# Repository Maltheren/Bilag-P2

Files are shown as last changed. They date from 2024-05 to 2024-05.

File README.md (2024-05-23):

# Bilag til P2 projektet ESD210
Alle eksterne bilag til P2 projektet for ESD210 hvor der kan findes følgende mapper:

### Kicad filer
Alle kredsløbsdiagrammer samt PCB designs. Under mappen /PDF kan alle schematics findes i pdf format.

### Kode produkt
De endelige 3 sketches for produktet. Det anbefales at åbne dem via platformIO.
Ellers kan den primære funktionskode findes i /src/main.cpp, samt de udviklede libraries under /lib.
Eksternt brugte libraries i dette projekt er:
- "Arduino.h"
- "RF24.h"

### Tests
Her forefindes de forskellige tests opdelt som enten samlet, Klokke eller MKF

### PC oscilloskop
For at visualisere de samples der tages af arduinoen på MKF-modulet benyttes følgende værktøj
https://x-io.co.uk/serial-oscilloscope/

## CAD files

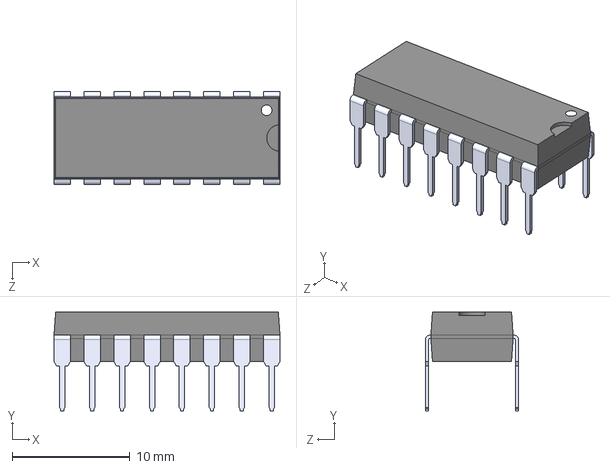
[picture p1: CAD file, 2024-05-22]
Kicad filer/MKFmodul/DG445CJ/DG445CJ.step
19.2 x 8.38 x 7.90 mm

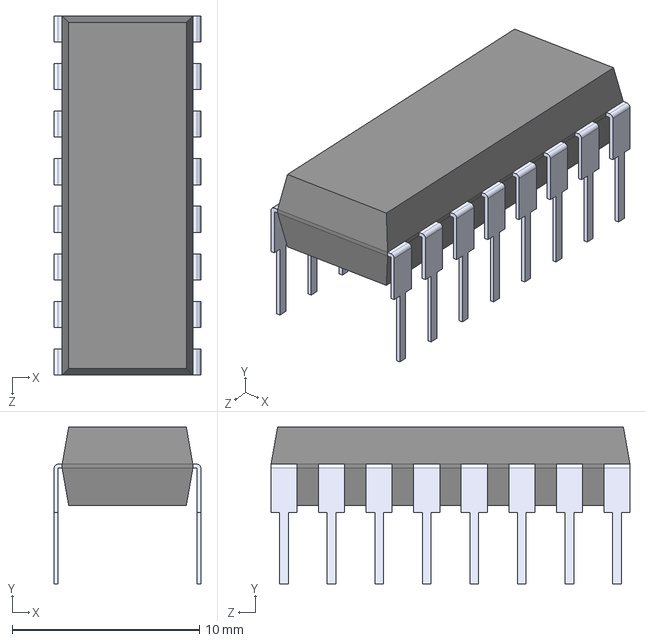
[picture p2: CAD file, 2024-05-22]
Kicad filer/PowerAddOn/PowerAddOn/MAX743CPE/MAX743CPE.step
7.83 x 8.38 x 19.2 mm

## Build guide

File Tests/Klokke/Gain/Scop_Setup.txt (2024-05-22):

TIME STEP:
125 = 1ms

VOLTAGE STEP:
CH1:  32 = 1V
CH2:  32 = 0.1V
GND	34	100
N	CH1	CH2

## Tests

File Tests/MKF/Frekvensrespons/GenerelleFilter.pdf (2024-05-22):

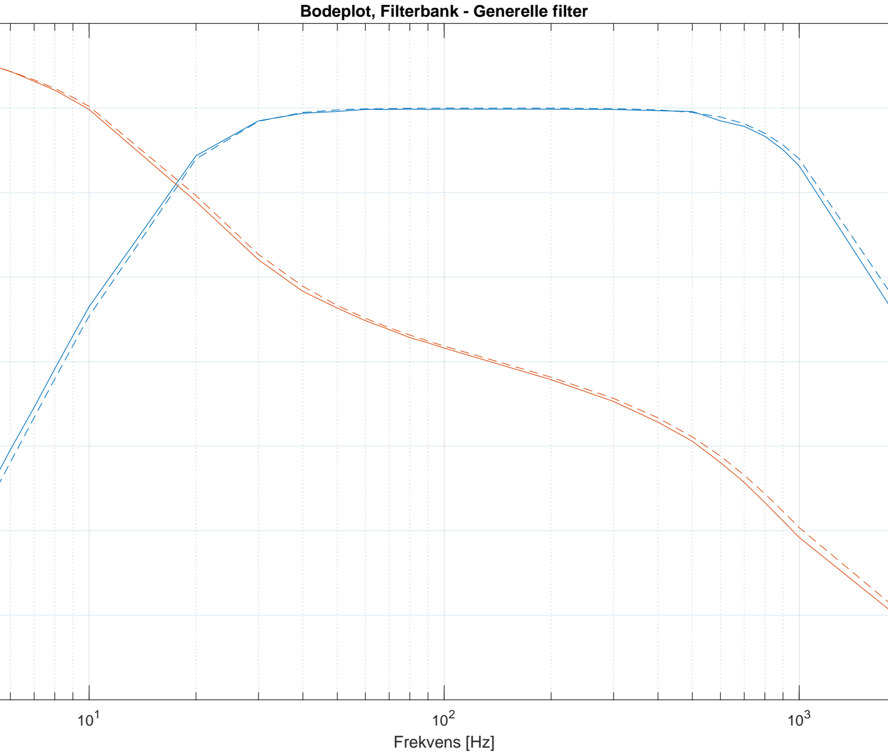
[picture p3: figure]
Frekvens [Hz]; Bodeplot, Filterbank - Generelle filter

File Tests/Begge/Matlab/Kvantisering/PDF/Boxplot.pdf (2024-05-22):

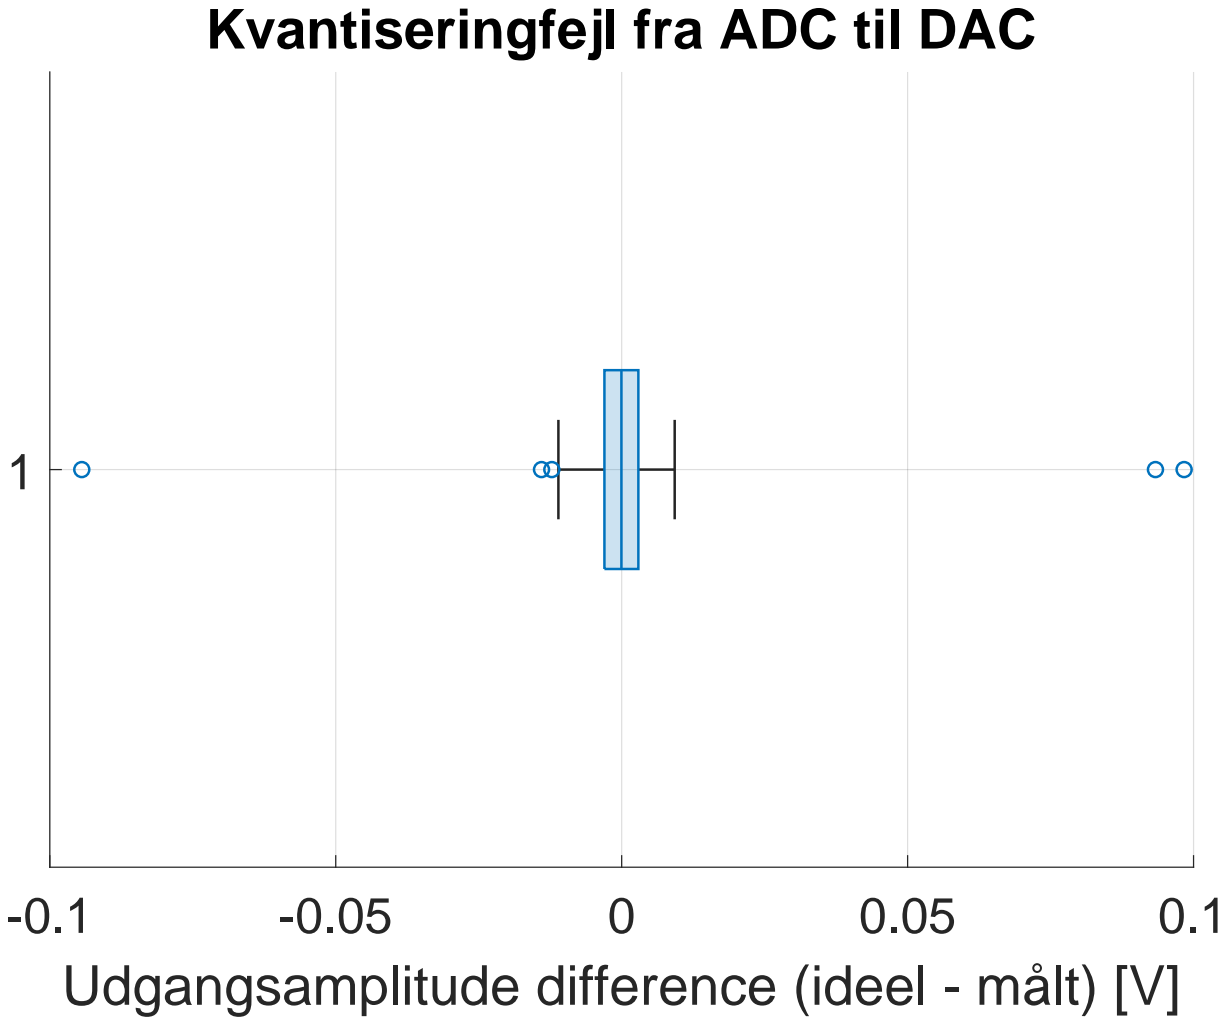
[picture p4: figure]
Kvantiseringfejl fra ADC til DAC

Udgangsamplitude difference (ideel - målt) [V]

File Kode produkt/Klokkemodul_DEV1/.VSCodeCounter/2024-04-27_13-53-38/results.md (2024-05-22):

# Summary

Date : 2024-04-27 13:53:38

Directory c:\\Users\\Malthe Sennels\\Documents\\ESD210\\Kode_Produkt\\Klokkemodul_DEV1

Total : 17 files,  393 codes, 148 comments, 179 blanks, all 720 lines

Summary / [Details](details.md) / [Diff Summary](diff.md) / [Diff Details](diff-details.md)

## Languages
| language | files | code | comment | blank | total |
| :--- | ---: | ---: | ---: | ---: | ---: |
| C++ | 15 | 377 | 137 | 173 | 687 |
| Ini | 1 | 14 | 11 | 5 | 30 |
| Markdown | 1 | 2 | 0 | 1 | 3 |

## Directories
| path | files | code | comment | blank | total |
| :--- | ---: | ---: | ---: | ---: | ---: |
| . | 17 | 393 | 148 | 179 | 720 |
| . (Files) | 1 | 14 | 11 | 5 | 30 |
| lib | 15 | 328 | 107 | 136 | 571 |
| lib\\DAC | 2 | 46 | 0 | 15 | 61 |
| lib\\GainController | 2 | 44 | 5 | 18 | 67 |
| lib\\HAL | 2 | 38 | 24 | 34 | 96 |
| lib\\JobQuerer | 2 | 63 | 39 | 24 | 126 |
| lib\\JobQuerer\\src | 2 | 63 | 39 | 24 | 126 |
| lib\\Ringbuffer | 2 | 33 | 11 | 7 | 51 |
| lib\\TurboAnalogRead | 3 | 43 | 26 | 22 | 91 |
| lib\\TurboAnalogRead (Files) | 1 | 2 | 0 | 1 | 3 |
| lib\\TurboAnalogRead\\src | 2 | 41 | 26 | 21 | 88 |
| lib\\X9C104 | 2 | 61 | 2 | 16 | 79 |
| src | 1 | 51 | 30 | 38 | 119 |

Summary / [Details](details.md) / [Diff Summary](diff.md) / [Diff Details](diff-details.md)

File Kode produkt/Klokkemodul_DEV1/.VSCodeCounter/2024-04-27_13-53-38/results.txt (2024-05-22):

Date : 2024-04-27 13:53:38
Directory : c:\Users\Malthe Sennels\Documents\ESD210\Kode_Produkt\Klokkemodul_DEV1
Total : 17 files,  393 codes, 148 comments, 179 blanks, all 720 lines

Languages
+----------+------------+------------+------------+------------+------------+
| language | files      | code       | comment    | blank      | total      |
+----------+------------+------------+------------+------------+------------+
| C++      |         15 |        377 |        137 |        173 |        687 |
| Ini      |          1 |         14 |         11 |          5 |         30 |
| Markdown |          1 |          2 |          0 |          1 |          3 |
+----------+------------+------------+------------+------------+------------+

Directories
+--------------------------------------------------------------------------------------------------------------+------------+------------+------------+------------+------------+
| path                                                                                                         | files      | code       | comment    | blank      | total      |
+--------------------------------------------------------------------------------------------------------------+------------+------------+------------+------------+------------+
| .                                                                                                            |         17 |        393 |        148 |        179 |        720 |
| . (Files)                                                                                                    |          1 |         14 |         11 |          5 |         30 |
| lib                                                                                                          |         15 |        328 |        107 |        136 |        571 |
| lib\DAC                                                                                                      |          2 |         46 |          0 |         15 |         61 |
| lib\GainController                                                                                           |          2 |         44 |          5 |         18 |         67 |
| lib\HAL                                                                                                      |          2 |         38 |         24 |         34 |         96 |
| lib\JobQuerer                                                                                                |          2 |         63 |         39 |         24 |        126 |
| lib\JobQuerer\src                                                                                            |          2 |         63 |         39 |         24 |        126 |
| lib\Ringbuffer                                                                                               |          2 |         33 |         11 |          7 |         51 |
| lib\TurboAnalogRead                                                                                          |          3 |         43 |         26 |         22 |         91 |
| lib\TurboAnalogRead (Files)                                                                                  |          1 |          2 |          0 |          1 |          3 |
| lib\TurboAnalogRead\src                                                                                      |          2 |         41 |         26 |         21 |         88 |
| lib\X9C104                                                                                                   |          2 |         61 |          2 |         16 |         79 |
| src                                                                                                          |          1 |         51 |         30 |         38 |        119 |
+--------------------------------------------------------------------------------------------------------------+------------+------------+------------+------------+------------+

Files
+--------------------------------------------------------------------------------------------------------------+----------+------------+------------+------------+------------+
| filename                                                                                                     | language | code       | comment    | blank      | total      |
+--------------------------------------------------------------------------------------------------------------+----------+------------+------------+------------+------------+
| c:\Users\Malthe Sennels\Documents\ESD210\Kode_Produkt\Klokkemodul_DEV1\lib\DAC\DAC.cpp                       | C++      |         39 |          0 |         15 |         54 |
| c:\Users\Malthe Sennels\Documents\ESD210\Kode_Produkt\Klokkemodul_DEV1\lib\DAC\DAC.h                         | C++      |          7 |          0 |          0 |          7 |
| c:\Users\Malthe Sennels\Documents\ESD210\Kode_Produkt\Klokkemodul_DEV1\lib\GainController\GainController.cpp | C++      |         27 |          1 |          9 |         37 |
| c:\Users\Malthe Sennels\Documents\ESD210\Kode_Produkt\Klokkemodul_DEV1\lib\GainController\GainController.h   | C++      |         17 |          4 |          9 |         30 |
| c:\Users\Malthe Sennels\Documents\ESD210\Kode_Produkt\Klokkemodul_DEV1\lib\HAL\HAL.cpp                       | C++      |         13 |          0 |          6 |         19 |
| c:\Users\Malthe Sennels\Documents\ESD210\Kode_Produkt\Klokkemodul_DEV1\lib\HAL\HAL.h                         | C++      |         25 |         24 |         28 |         77 |
| c:\Users\Malthe Sennels\Documents\ESD210\Kode_Produkt\Klokkemodul_DEV1\lib\JobQuerer\src\JobQueuer.cpp       | C++      |         46 |         22 |         12 |         80 |
| c:\Users\Malthe Sennels\Documents\ESD210\Kode_Produkt\Klokkemodul_DEV1\lib\JobQuerer\src\JobQueuer.h         | C++      |         17 |         17 |         12 |         46 |
| c:\Users\Malthe Sennels\Documents\ESD210\Kode_Produkt\Klokkemodul_DEV1\lib\Ringbuffer\Ringbuffer.cpp         | C++      |         21 |         11 |          4 |         36 |
| c:\Users\Malthe Sennels\Documents\ESD210\Kode_Produkt\Klokkemodul_DEV1\lib\Ringbuffer\Ringbuffer.h           | C++      |         12 |          0 |          3 |         15 |
| c:\Users\Malthe Sennels\Documents\ESD210\Kode_Produkt\Klokkemodul_DEV1\lib\TurboAnalogRead\README.md         | Markdown |          2 |          0 |          1 |          3 |
| c:\Users\Malthe Sennels\Documents\ESD210\Kode_Produkt\Klokkemodul_DEV1\lib\TurboAnalogRead\src\TurboAnal.cpp | C++      |         32 |          9 |         16 |         57 |
| c:\Users\Malthe Sennels\Documents\ESD210\Kode_Produkt\Klokkemodul_DEV1\lib\TurboAnalogRead\src\TurboAnal.h   | C++      |          9 |         17 |          5 |         31 |
| c:\Users\Malthe Sennels\Documents\ESD210\Kode_Produkt\Klokkemodul_DEV1\lib\X9C104\X9C104.cpp                 | C++      |         49 |          0 |         14 |         63 |
| c:\Users\Malthe Sennels\Documents\ESD210\Kode_Produkt\Klokkemodul_DEV1\lib\X9C104\X9C104.h                   | C++      |         12 |          2 |          2 |         16 |
| c:\Users\Malthe Sennels\Documents\ESD210\Kode_Produkt\Klokkemodul_DEV1\platformio.ini                        | Ini      |         14 |         11 |          5 |         30 |
| c:\Users\Malthe Sennels\Documents\ESD210\Kode_Produkt\Klokkemodul_DEV1\src\main.cpp                          | C++      |         51 |         30 |         38 |        119 |
| Total                                                                                                        |          |        393 |        148 |        179 |        720 |
+--------------------------------------------------------------------------------------------------------------+----------+------------+------------+------------+------------+

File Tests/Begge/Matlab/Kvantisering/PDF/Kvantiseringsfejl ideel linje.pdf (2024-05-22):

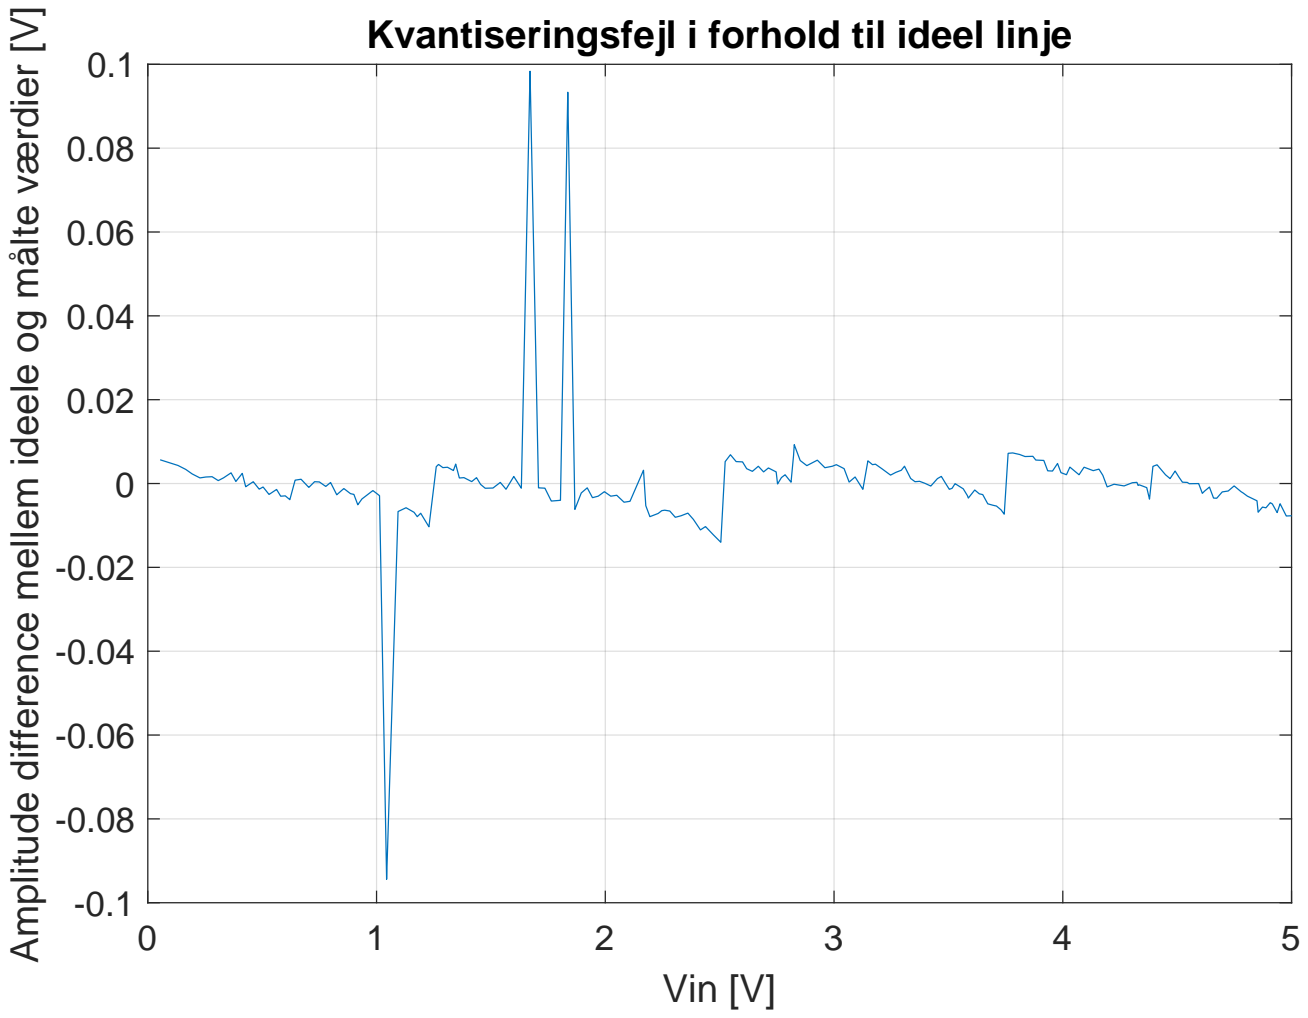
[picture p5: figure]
Vin [V]

Amplitude difference mellem ideele og målte værdier [V] Kvantiseringsfejl i forhold til ideel linje

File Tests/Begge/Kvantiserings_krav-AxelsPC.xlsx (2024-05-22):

Diff | Vin | Vout | Agilent 34401A 6½ Digit Multimeter
0.0160 | 0.0540 | 0.0380 | B1-101-J-2 og B1-101-J-2
0.0260 | 0.1320 | 0.1060
0.0300 | 0.1660 | 0.1360 | PowerSupply HM7042-3
0.0330 | 0.1940 | 0.1610 | Lab bord 2
0.0370 | 0.2280 | 0.1910
0.0410 | 0.2540 | 0.2130
0.0450 | 0.2810 | 0.2360
0.0480 | 0.3080 | 0.2600
0.0520 | 0.3310 | 0.2790
0.0580 | 0.3640 | 0.3060
0.0590 | 0.3850 | 0.3260
0.0650 | 0.4130 | 0.3480
0.0640 | 0.4280 | 0.3640
0.0700 | 0.4610 | 0.3910
0.0720 | 0.4870 | 0.4150
0.0750 | 0.5040 | 0.4290
0.0770 | 0.5300 | 0.4530
0.0830 | 0.5630 | 0.4800
0.0840 | 0.5810 | 0.4970
0.0870 | 0.6010 | 0.5140
0.0890 | 0.6210 | 0.5320
0.0970 | 0.6440 | 0.5470
0.1010 | 0.6700 | 0.5690
0.1040 | 0.7040 | 0.6000
0.1090 | 0.7290 | 0.6200
0.1120 | 0.7500 | 0.6380
0.1150 | 0.7780 | 0.6630
0.1190 | 0.7990 | 0.6800
0.1200 | 0.8260 | 0.7060
0.1260 | 0.8570 | 0.7310
0.1290 | 0.8860 | 0.7570
0.1310 | 0.9010 | 0.7700
0.1310 | 0.9180 | 0.7870
0.1350 | 0.9360 | 0.8010
0.1440 | 0.9840 | 0.8400
0.1470 | 1.0130 | 0.8660
0.0600 | 1.0440 | 0.9840
0.1550 | 1.0940 | 0.9390
0.1610 | 1.1290 | 0.9680
0.1650 | 1.1640 | 0.9990
0.1660 | 1.1780 | 1.0120
0.1690 | 1.1930 | 1.0240
0.1710 | 1.2290 | 1.0580
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

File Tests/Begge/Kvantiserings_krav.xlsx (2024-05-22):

Diff | Vin | Vout | Procent | Anden procent | Tredje procent | 0.05 | Agilent 34401A 6½ Digit Multimeter
0.0160 | 0.0540 | 0.0380 | 42.10526316 | 70.37037037 |  |  | B1-101-J-2 og B1-101-J-2
0.0260 | 0.1320 | 0.1060 | 24.52830189 | 80.3030303
0.0300 | 0.1660 | 0.1360 | 22.05882353 | 81.92771084 |  |  | PowerSupply HM7042-3
0.0330 | 0.1940 | 0.1610 | 20.49689441 | 82.98969072 |  |  | Lab bord 2
0.0370 | 0.2280 | 0.1910 | 19.37172775 | 83.77192982
0.0410 | 0.2540 | 0.2130 | 19.24882629 | 83.85826772
0.0450 | 0.2810 | 0.2360 | 19.06779661 | 83.98576512
0.0480 | 0.3080 | 0.2600 | 18.46153846 | 84.41558442
0.0520 | 0.3310 | 0.2790 | 18.63799283 | 84.29003021
0.0580 | 0.3640 | 0.3060 | 18.95424837 | 84.06593407
0.0590 | 0.3850 | 0.3260 | 18.09815951 | 84.67532468
0.0650 | 0.4130 | 0.3480 | 18.67816092 | 84.26150121
0.0640 | 0.4280 | 0.3640 | 17.58241758 | 85.04672897
0.0700 | 0.4610 | 0.3910 | 17.9028133 | 84.81561822
0.0720 | 0.4870 | 0.4150 | 17.34939759 | 85.21560575
0.0750 | 0.5040 | 0.4290 | 17.48251748 | 85.11904762
0.0770 | 0.5300 | 0.4530 | 16.99779249 | 85.47169811
0.0830 | 0.5630 | 0.4800 | 17.29166667 | 85.25754885
0.0840 | 0.5810 | 0.4970 | 16.90140845 | 85.54216867
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

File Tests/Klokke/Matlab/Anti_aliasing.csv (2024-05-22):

Frequency Log(Hz) | Gain (dB) | Phase (deg)
1.00010441154522 | -0.0755059268770044 | -0.468755780057126
1.01017684989716 | -0.0804092249655539 | -0.707637762284573
1.02002096711708 | -0.0793540430161215 | -0.553636372563628
1.03009998339997 | -0.0727163140612757 | -0.59086179621073
1.03995038360925 | -0.103404899460902 | -0.68559063690119
1.05001508903831 | -0.0521366469052955 | -0.597248702201664
1.05985181982658 | -0.0890899774555884 | -0.615335713545116
1.06988409225755 | -0.10431189232152 | -0.56715485833256
1.08009364755968 | -0.0876232732946506 | -0.756384908477297
1.09006869520106 | -0.104903315679289 | -0.696187352977774
1.09981976674463 | -0.112980787842304 | -0.64656706352112
1.11011068352401 | -0.123376923265336 | -0.797928439543142
1.12016338353543 | -0.098296256568499 | -0.74261121967203
1.12998864632666 | -0.0963835626482901 | -0.780764504027877
1.13994833382499 | -0.0998227537160254 | -0.680949938352071
1.15002845017567 | -0.0917975086893228 | -0.804883931296215
1.1598799011097 | -0.105430821068148 | -0.720465710646599
1.16984122041681 | -0.108077854134989 | -0.95093918470508
1.17990004057843 | -0.0839611594759843 | -0.849576513058788
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

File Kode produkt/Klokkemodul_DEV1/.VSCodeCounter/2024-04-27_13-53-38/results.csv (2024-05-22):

filename | "language" | "C++" | "Ini" | "Markdown" | "comment" | "blank" | "total"
c:\Users\Malthe Sennels\Documents\ESD210\Kode_Produkt\Klokkemodul_DEV1\lib\DAC\DAC.cpp | "C++" | 39 | 0 | 0 | 0 | 15 | 54
c:\Users\Malthe Sennels\Documents\ESD210\Kode_Produkt\Klokkemodul_DEV1\lib\DAC\DAC.h | "C++" | 7 | 0 | 0 | 0 | 0 | 7
c:\Users\Malthe Sennels\Documents\ESD210\Kode_Produkt\Klokkemodul_DEV1\lib\GainController\GainController.cpp | "C++" | 27 | 0 | 0 | 1 | 9 | 37
c:\Users\Malthe Sennels\Documents\ESD210\Kode_Produkt\Klokkemodul_DEV1\lib\GainController\GainController.h | "C++" | 17 | 0 | 0 | 4 | 9 | 30
c:\Users\Malthe Sennels\Documents\ESD210\Kode_Produkt\Klokkemodul_DEV1\lib\HAL\HAL.cpp | "C++" | 13 | 0 | 0 | 0 | 6 | 19
c:\Users\Malthe Sennels\Documents\ESD210\Kode_Produkt\Klokkemodul_DEV1\lib\HAL\HAL.h | "C++" | 25 | 0 | 0 | 24 | 28 | 77
c:\Users\Malthe Sennels\Documents\ESD210\Kode_Produkt\Klokkemodul_DEV1\lib\JobQuerer\src\JobQueuer.cpp | "C++" | 46 | 0 | 0 | 22 | 12 | 80
c:\Users\Malthe Sennels\Documents\ESD210\Kode_Produkt\Klokkemodul_DEV1\lib\JobQuerer\src\JobQueuer.h | "C++" | 17 | 0 | 0 | 17 | 12 | 46
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

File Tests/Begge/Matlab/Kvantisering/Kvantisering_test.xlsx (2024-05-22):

Måling nr. | Diff | Vin | Vout
1 | 0.0160 | 0.0540 | 0.0380
2 | 0.0260 | 0.1320 | 0.1060
3 | 0.0300 | 0.1660 | 0.1360
4 | 0.0330 | 0.1940 | 0.1610
5 | 0.0370 | 0.2280 | 0.1910
6 | 0.0410 | 0.2540 | 0.2130
7 | 0.0450 | 0.2810 | 0.2360
8 | 0.0480 | 0.3080 | 0.2600
9 | 0.0520 | 0.3310 | 0.2790
10 | 0.0580 | 0.3640 | 0.3060
11 | 0.0590 | 0.3850 | 0.3260
12 | 0.0650 | 0.4130 | 0.3480
13 | 0.0640 | 0.4280 | 0.3640
14 | 0.0700 | 0.4610 | 0.3910
15 | 0.0720 | 0.4870 | 0.4150
16 | 0.0750 | 0.5040 | 0.4290
17 | 0.0770 | 0.5300 | 0.4530
18 | 0.0830 | 0.5630 | 0.4800
19 | 0.0840 | 0.5810 | 0.4970
20 | 0.0870 | 0.6010 | 0.5140
21 | 0.0890 | 0.6210 | 0.5320
22 | 0.0970 | 0.6440 | 0.5470
23 | 0.1010 | 0.6700 | 0.5690
24 | 0.1040 | 0.7040 | 0.6000
25 | 0.1090 | 0.7290 | 0.6200
26 | 0.1120 | 0.7500 | 0.6380
27 | 0.1150 | 0.7780 | 0.6630
28 | 0.1190 | 0.7990 | 0.6800
29 | 0.1200 | 0.8260 | 0.7060
30 | 0.1260 | 0.8570 | 0.7310
31 | 0.1290 | 0.8860 | 0.7570
32 | 0.1310 | 0.9010 | 0.7700
33 | 0.1310 | 0.9180 | 0.7870
34 | 0.1350 | 0.9360 | 0.8010
35 | 0.1440 | 0.9840 | 0.8400
36 | 0.1470 | 1.0130 | 0.8660
37 | 0.0600 | 1.0440 | 0.9840
38 | 0.1550 | 1.0940 | 0.9390
39 | 0.1610 | 1.1290 | 0.9680
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

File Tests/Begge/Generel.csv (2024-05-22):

Frequency Log(Hz) | Gain (dB) | Phase (deg)
1.00010441154522 | -12.011209132403 | -25.372145232961
1.02002096711708 | -11.057631405582 | -32.2919063222562
1.03995038360925 | -10.0916352961434 | -38.5096548936072
1.05985181982658 | -9.17540103233117 | -45.6148119474531
1.08009364755968 | -8.32330478253778 | -53.216740103655
1.09981976674463 | -7.52966253259223 | -60.5004757203305
1.12016338353543 | -6.63609525423683 | -68.5225080606208
1.13994833382499 | -5.95473503977451 | -76.0380994635946
1.1598799011097 | -5.06066912487525 | -84.4735313178523
1.17990004057843 | -4.50148166705586 | -92.0401407434262
1.19995760707635 | -3.79249389946553 | -100.736050170231
1.22000782988254 | -3.14617872903284 | -109.12937914409
1.24001176959216 | -2.53886367295844 | -117.827652422897
1.25993577678249 | -1.97296712217803 | -126.614845620476
1.28000575955782 | -1.40962626590904 | -136.046846046879
1.29991959667752 | -0.92818071587597 | -144.926179851604
1.31989067760814 | -0.442175762445809 | -154.541640800438
1.34009406369643 | -0.0708613806842722 | -163.690493427714
1.36003523728506 | 0.249982135736483 | -173.026542914195
1.37991109385924 | 0.612284478889098 | 177.066773133543
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

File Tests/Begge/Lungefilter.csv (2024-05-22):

Frequency Log(Hz) | Gain (dB) | Phase (deg)
1.00010441154522 | -55.9261696999814 | -20.7721118011987
1.02002096711708 | -53.6883660840568 | -13.825994332185
1.03995038360925 | -52.1594373691031 | 25.2647635117457
1.05985181982658 | -54.1989084746125 | 20.2276534975703
1.08009364755968 | -50.250116929712 | -5.44043174829694
1.09981976674463 | -52.6360730281625 | -3.42366888048387
1.12016338353543 | -48.326949586986 | 7.307493379687
1.13994833382499 | -48.2964418945681 | -37.1265541000624
1.1598799011097 | -45.2823229453974 | -24.4185030230016
1.17990004057843 | -43.9187798089575 | -35.215589918315
1.19995760707635 | -42.9080161015582 | -43.637364050171
1.22000782988254 | -41.0730085905207 | -43.0160499967187
1.24001176959216 | -40.33701875164 | -51.012823079157
1.25993577678249 | -40.0271600574216 | -58.2004727442881
1.28000575955782 | -38.5041926650283 | -65.2623711925689
1.29991959667752 | -36.9277106304643 | -65.7469781875511
1.31989067760814 | -36.935188439426 | -72.2008939324089
1.34009406369643 | -36.2567035615642 | -84.3759022850898
1.36003523728506 | -34.5662136985451 | -75.9573418335712
1.37991109385924 | -34.0010366819719 | -95.1024258009934
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

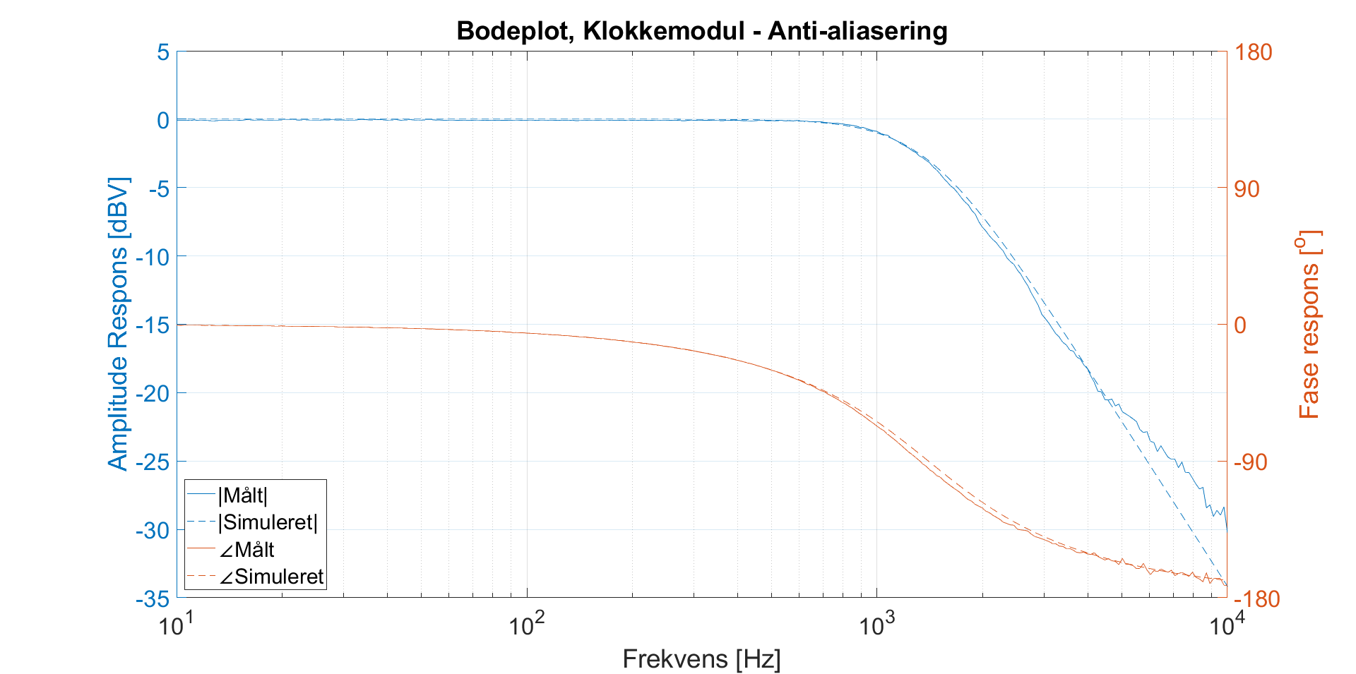
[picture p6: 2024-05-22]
Tests/Klokke/Anti-aliasering_bode.png

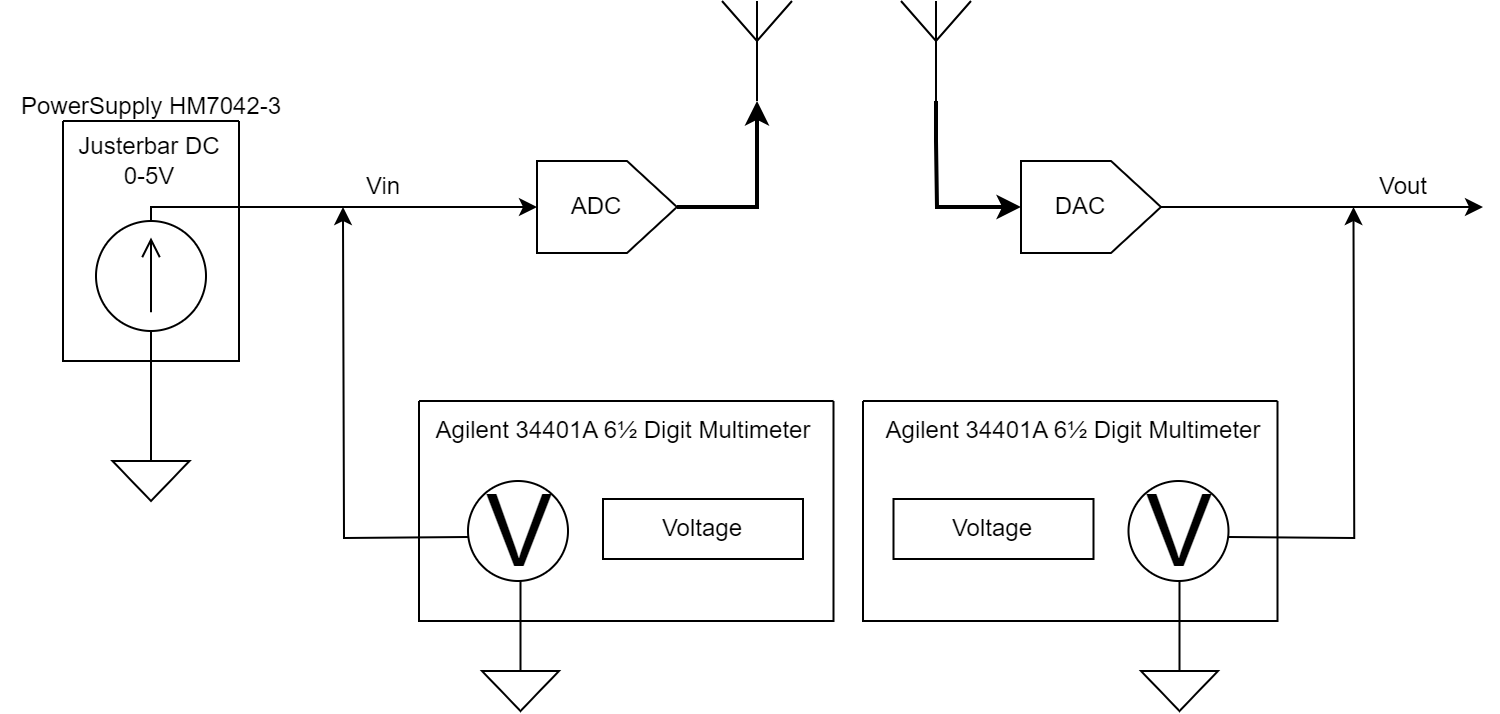
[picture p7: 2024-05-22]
Tests/Begge/TestSetup_KvantiseringsFejl.drawio.png

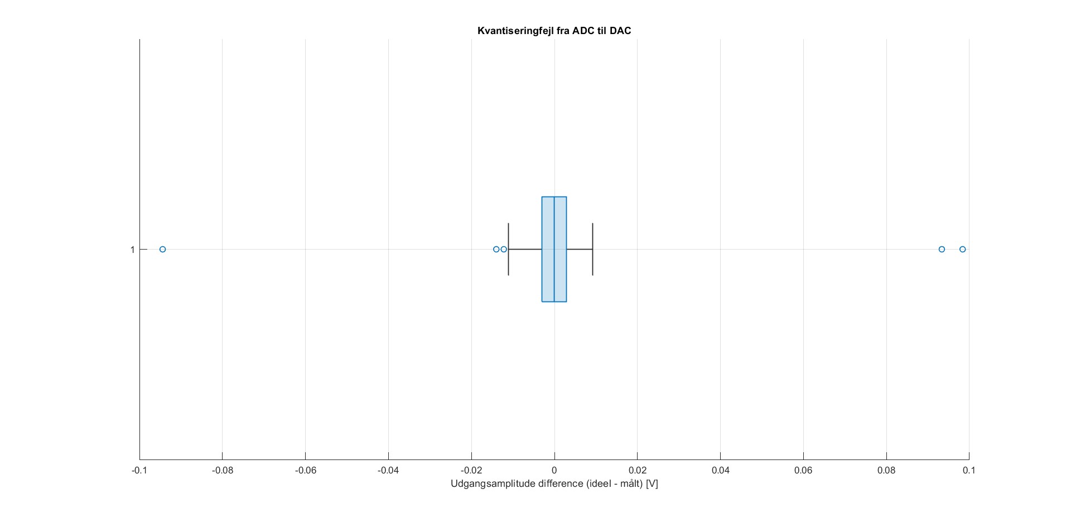
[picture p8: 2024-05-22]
Tests/Begge/Matlab/Kvantisering/Billeder/Kvantiseringsfejl_BoxPlot.jpg

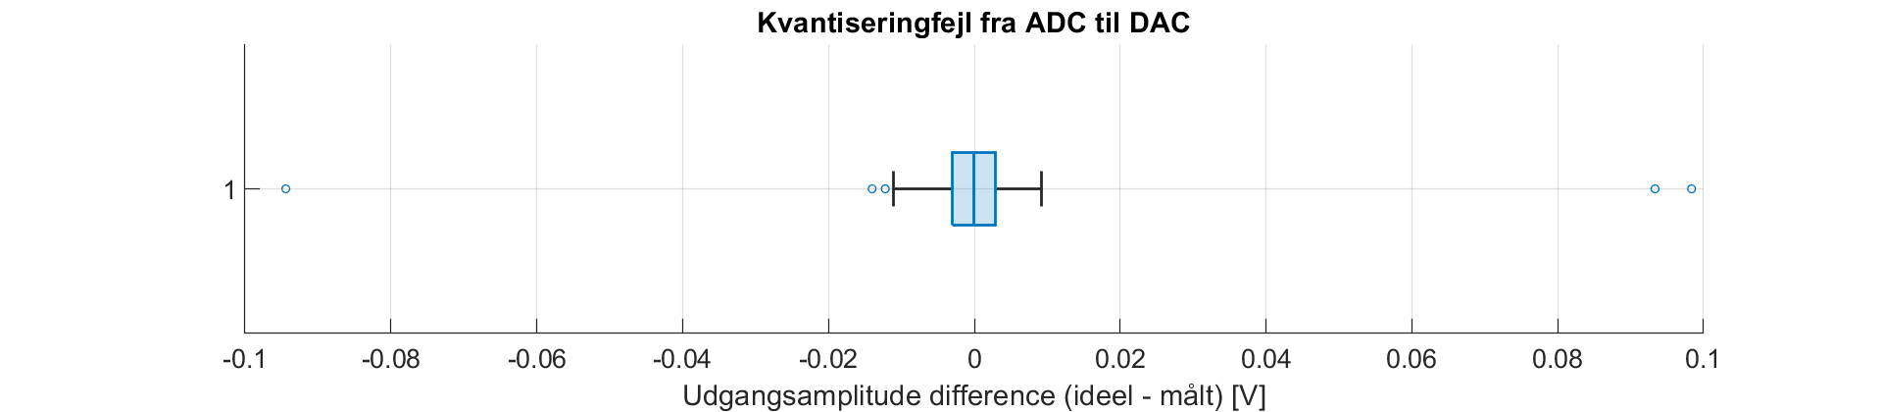
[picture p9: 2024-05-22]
Tests/Begge/Matlab/Kvantisering/Billeder/boxplot.png

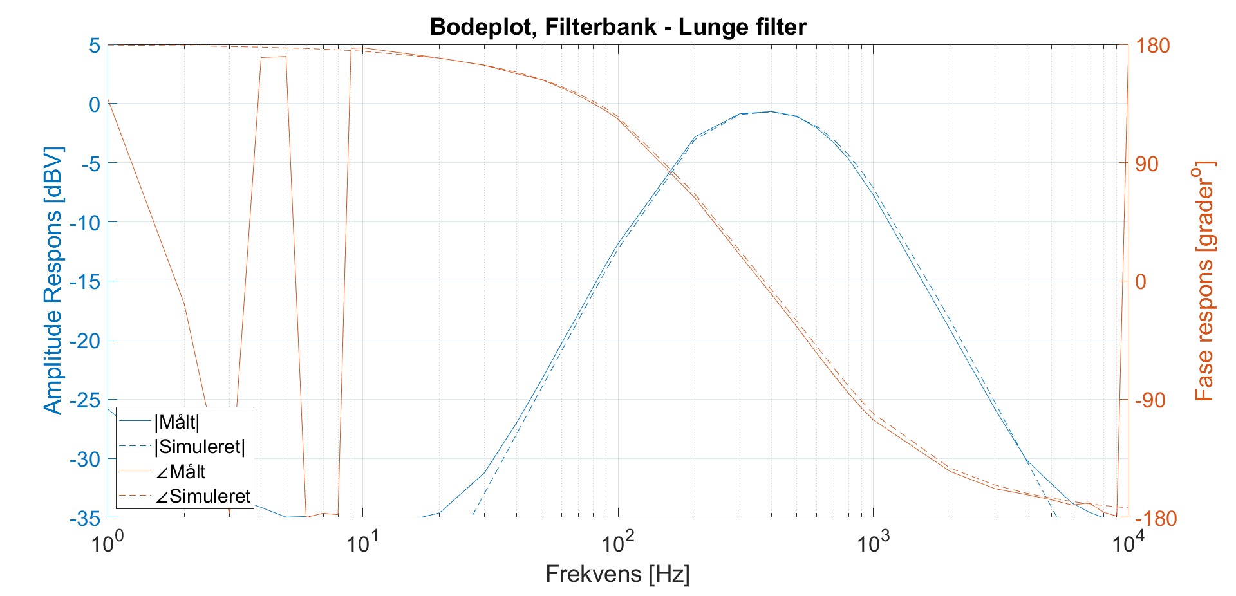
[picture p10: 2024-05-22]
Tests/MKF/Frekvensrespons/LungeFilter.jpg

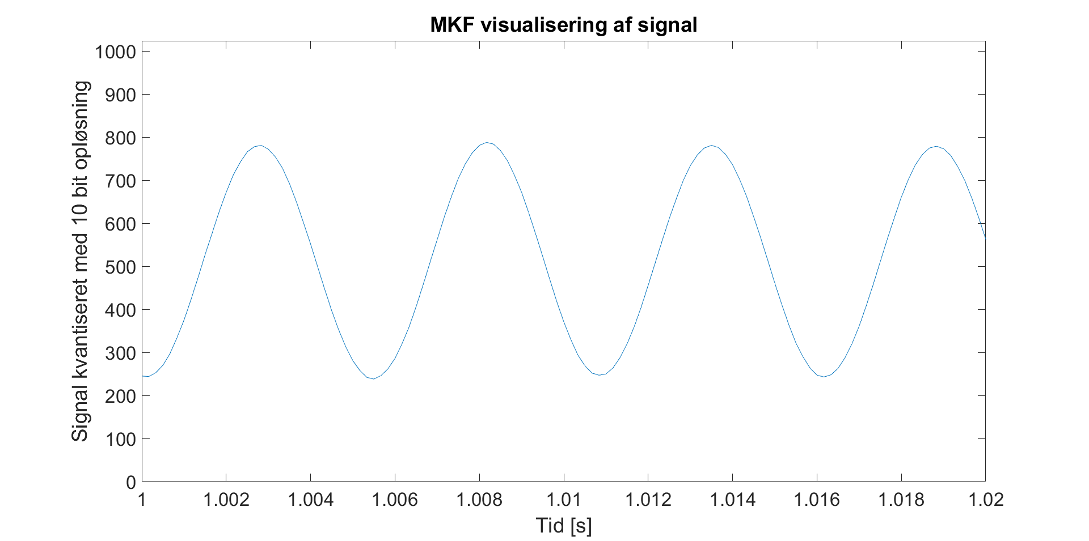
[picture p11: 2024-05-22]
Tests/Begge/Matlab/ScopeMeas/MKF visualisering af signal.png

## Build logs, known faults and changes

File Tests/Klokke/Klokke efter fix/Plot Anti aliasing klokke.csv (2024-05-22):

Frequency Log(Hz) | Gain (dB) | Phase (deg)
1.00010441154522 | -0.0555770347039578 | -0.535423069808453
1.01017684989716 | -0.0646500804799451 | -0.591944478238116
1.02002096711708 | -0.067976028752183 | -0.636422623407913
1.03009998339997 | -0.055471861064218 | -0.639633558016523
1.03995038360925 | -0.053593645790746 | -0.630651915697408
1.05001508903831 | -0.061378747734915 | -0.519543322011613
1.05985181982658 | -0.0641284166190814 | -0.67377972023904
1.06988409225755 | -0.0511160294597881 | -0.750617287213503
1.08009364755968 | -0.0558265152021361 | -0.668379911840307
1.09006869520106 | -0.0595937932167184 | -0.710354456472006
1.09981976674463 | -0.0622755443427763 | -0.728502952624024
1.11011068352401 | -0.0599085150547775 | -0.727972251631557
1.12016338353543 | -0.0681186785565105 | -0.768669262105791
1.12998864632666 | -0.0645027288812712 | -0.739001236080537
1.13994833382499 | -0.0594527981289591 | -0.789543363896919
1.15002845017567 | -0.0582621912032453 | -0.842623960429923
1.1598799011097 | -0.0574022192392623 | -0.814048734938113
1.16984122041681 | -0.0547316684907893 | -0.86167429829168
1.17990004057843 | -0.0623359441388386 | -0.837447210178718
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

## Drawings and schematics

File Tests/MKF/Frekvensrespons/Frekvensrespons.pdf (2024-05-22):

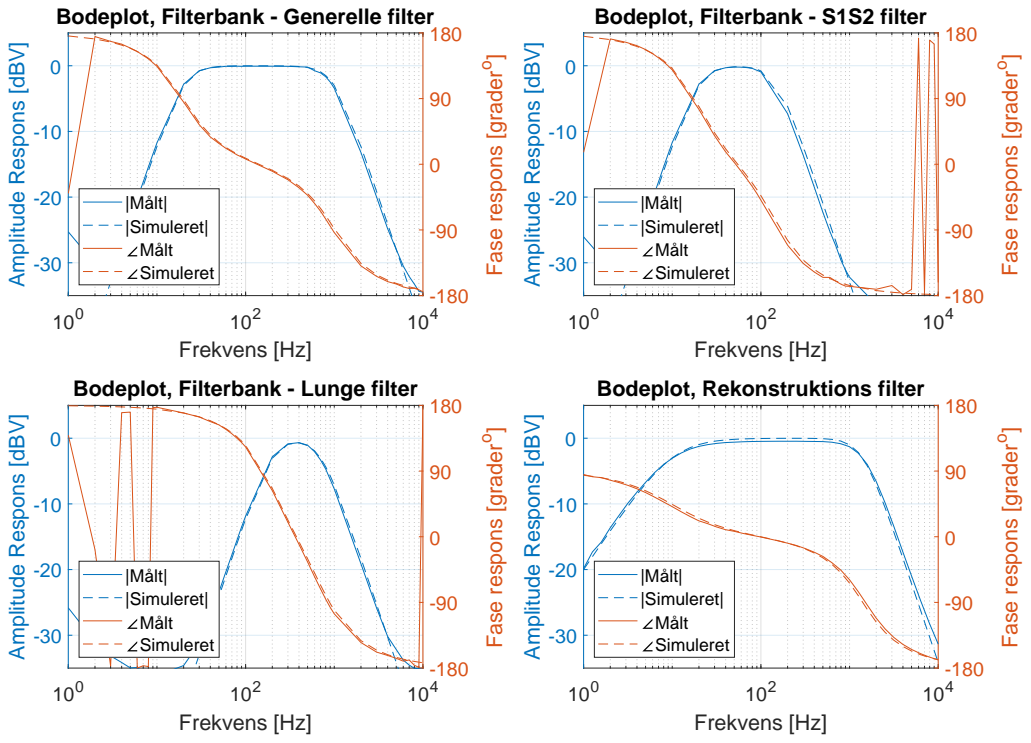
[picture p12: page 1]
Frekvens [Hz]; |Målt| |Simuleret| Målt Simuleret

Bodeplot, Filterbank - Generelle filter

Bodeplot, Filterbank - S1S2 filter

Amplitude Respons [dBV]

Fase respons [grader

Bodeplot, Filterbank - Lunge filter

Bodeplot, Rekonstruktions filter

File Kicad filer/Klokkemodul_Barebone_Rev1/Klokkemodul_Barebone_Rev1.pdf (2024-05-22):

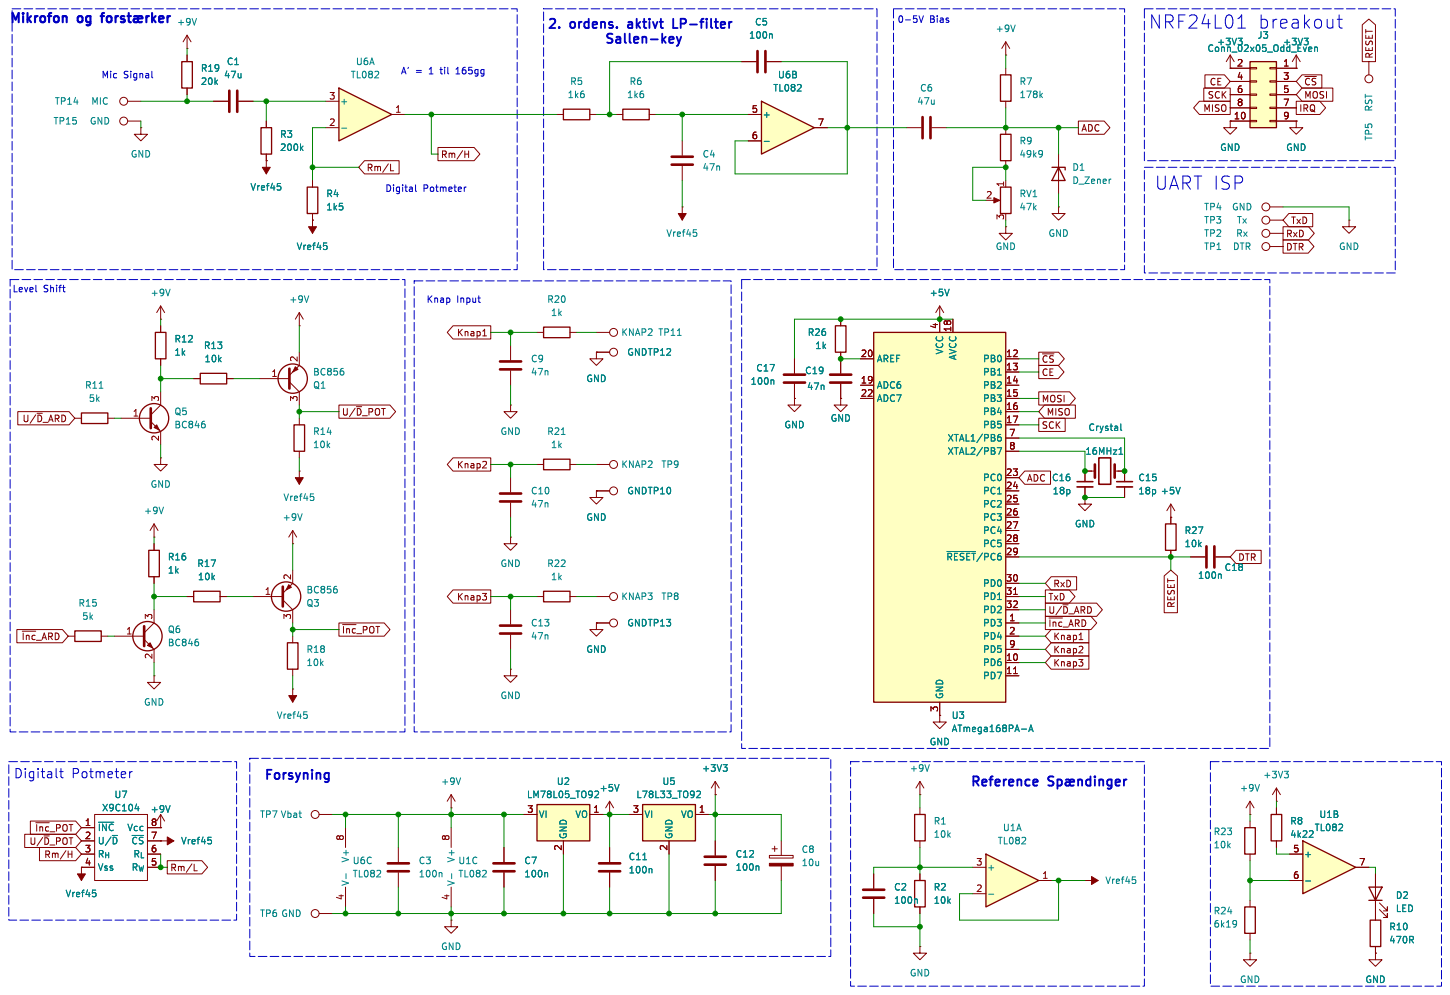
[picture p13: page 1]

2. ordens. aktivt LP-filter

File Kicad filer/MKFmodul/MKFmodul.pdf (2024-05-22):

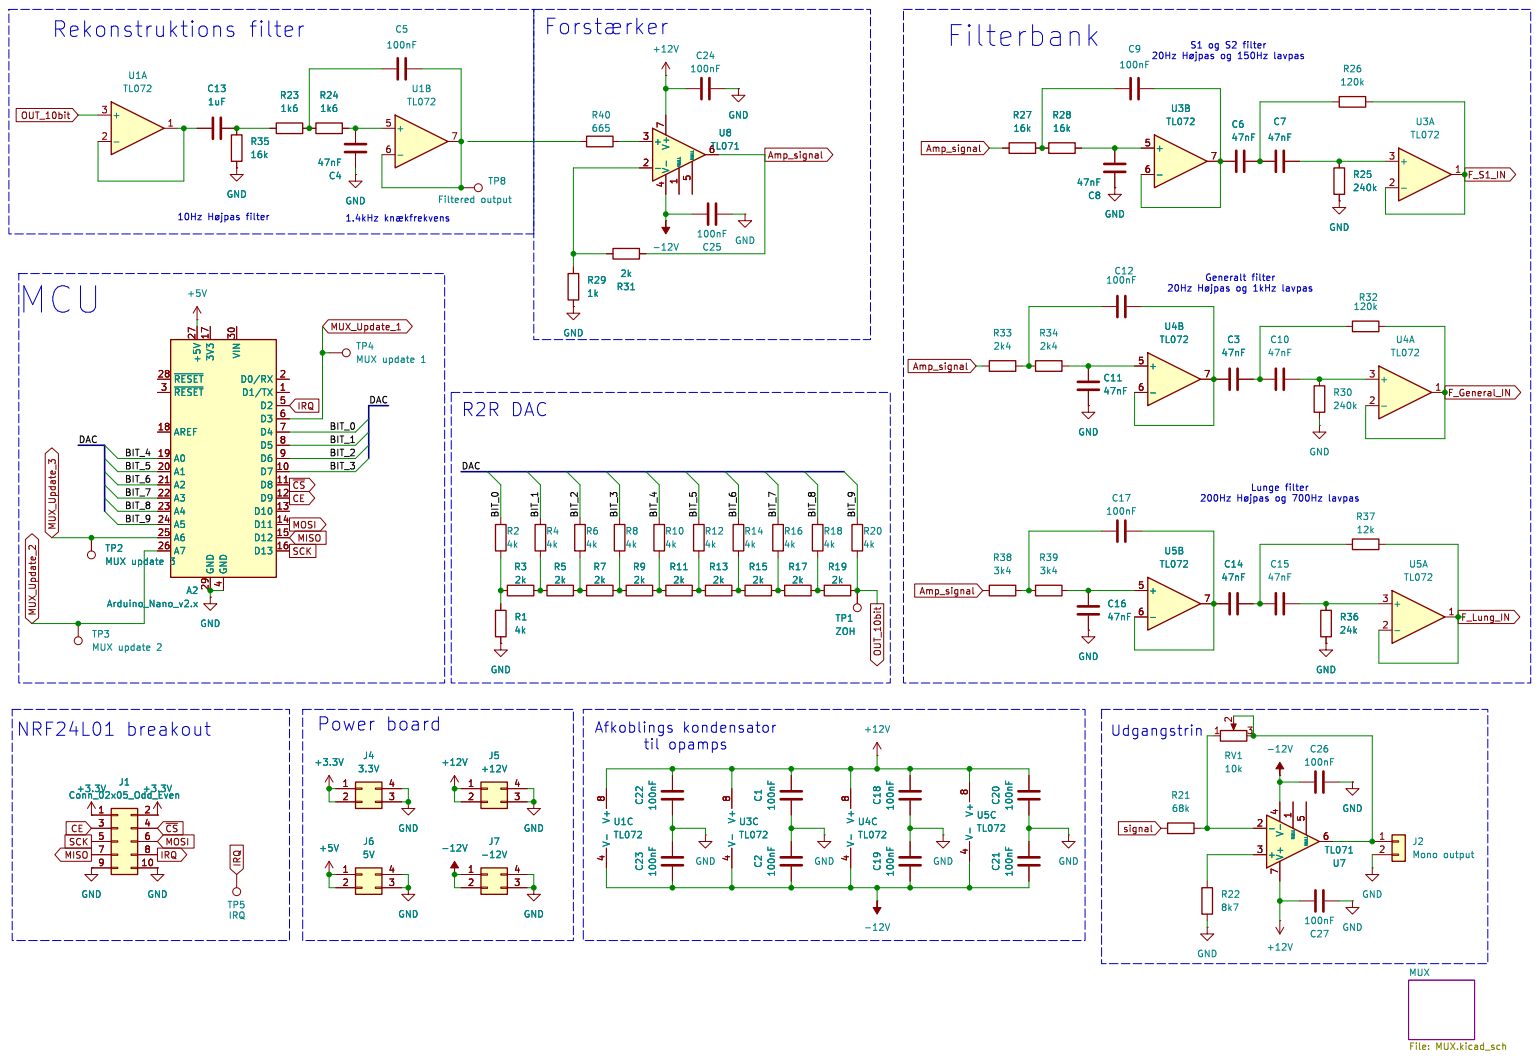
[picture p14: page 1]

Generalt filter 20Hz þÿHøjpas og 1kHz lavpas

Lunge filter 200Hz þÿHøjpas og 700Hz lavpas

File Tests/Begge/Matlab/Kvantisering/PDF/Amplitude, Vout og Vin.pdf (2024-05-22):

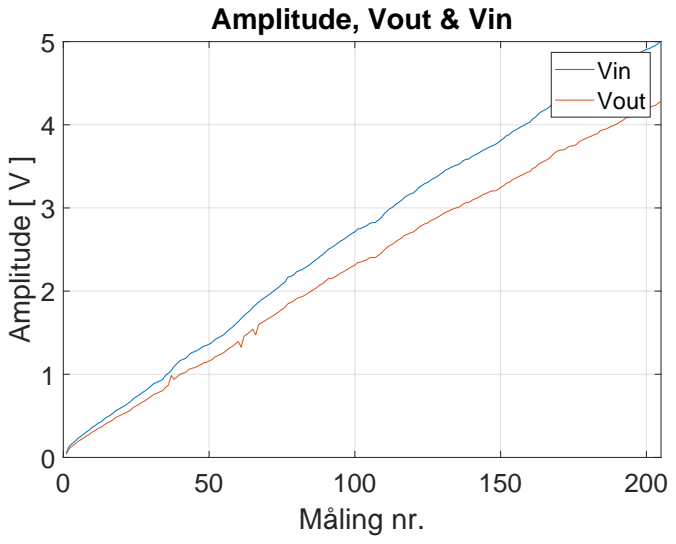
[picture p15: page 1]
Måling nr.; Amplitude [ V ]; Vin Vout

Amplitude, Vout & Vin

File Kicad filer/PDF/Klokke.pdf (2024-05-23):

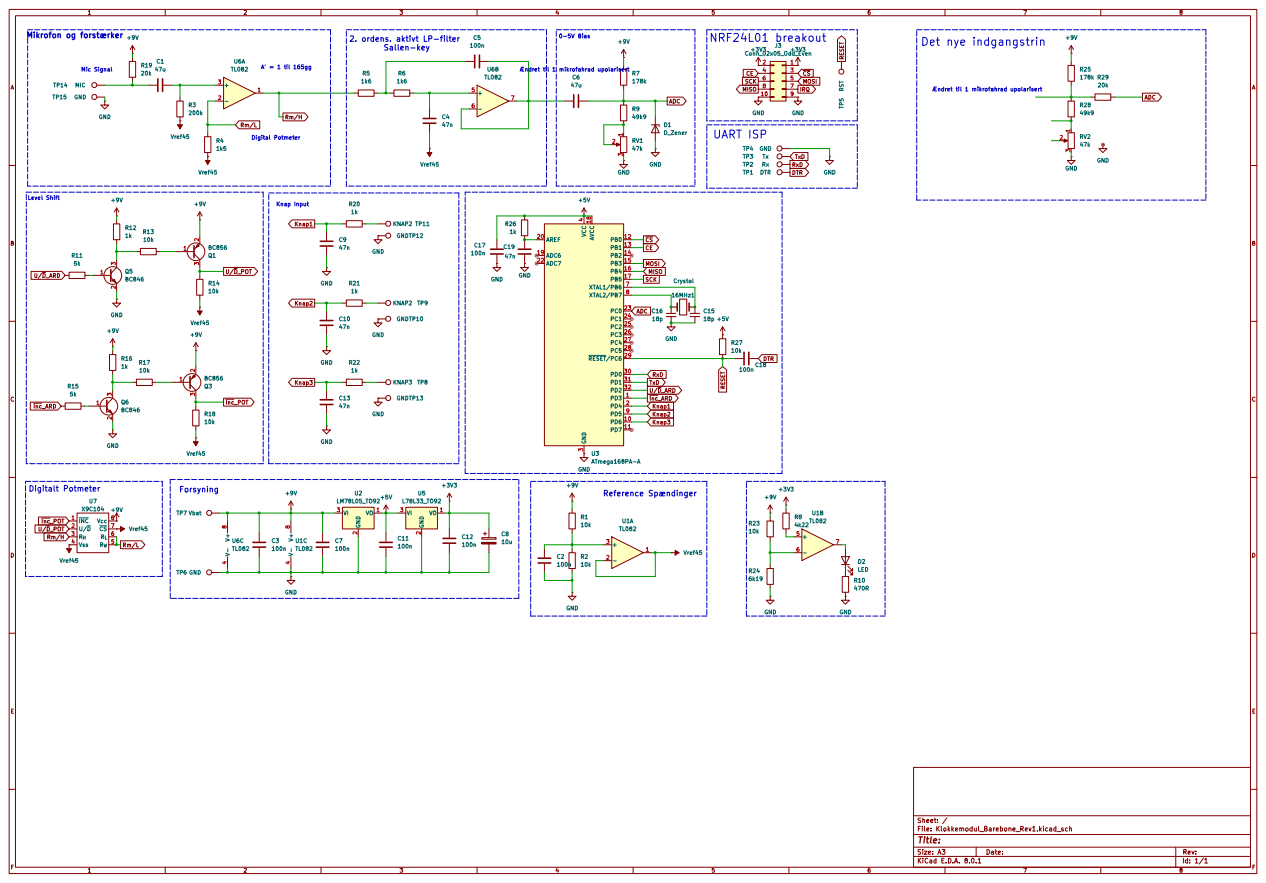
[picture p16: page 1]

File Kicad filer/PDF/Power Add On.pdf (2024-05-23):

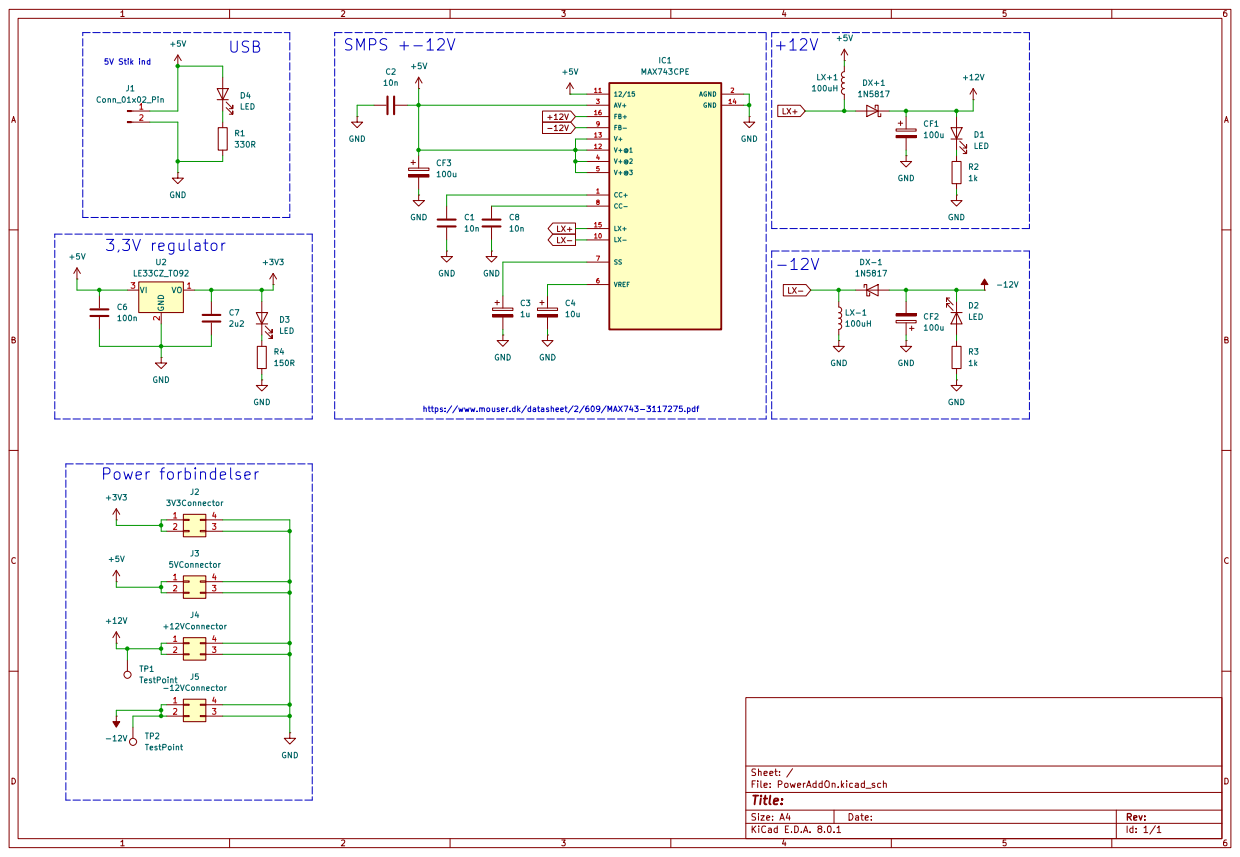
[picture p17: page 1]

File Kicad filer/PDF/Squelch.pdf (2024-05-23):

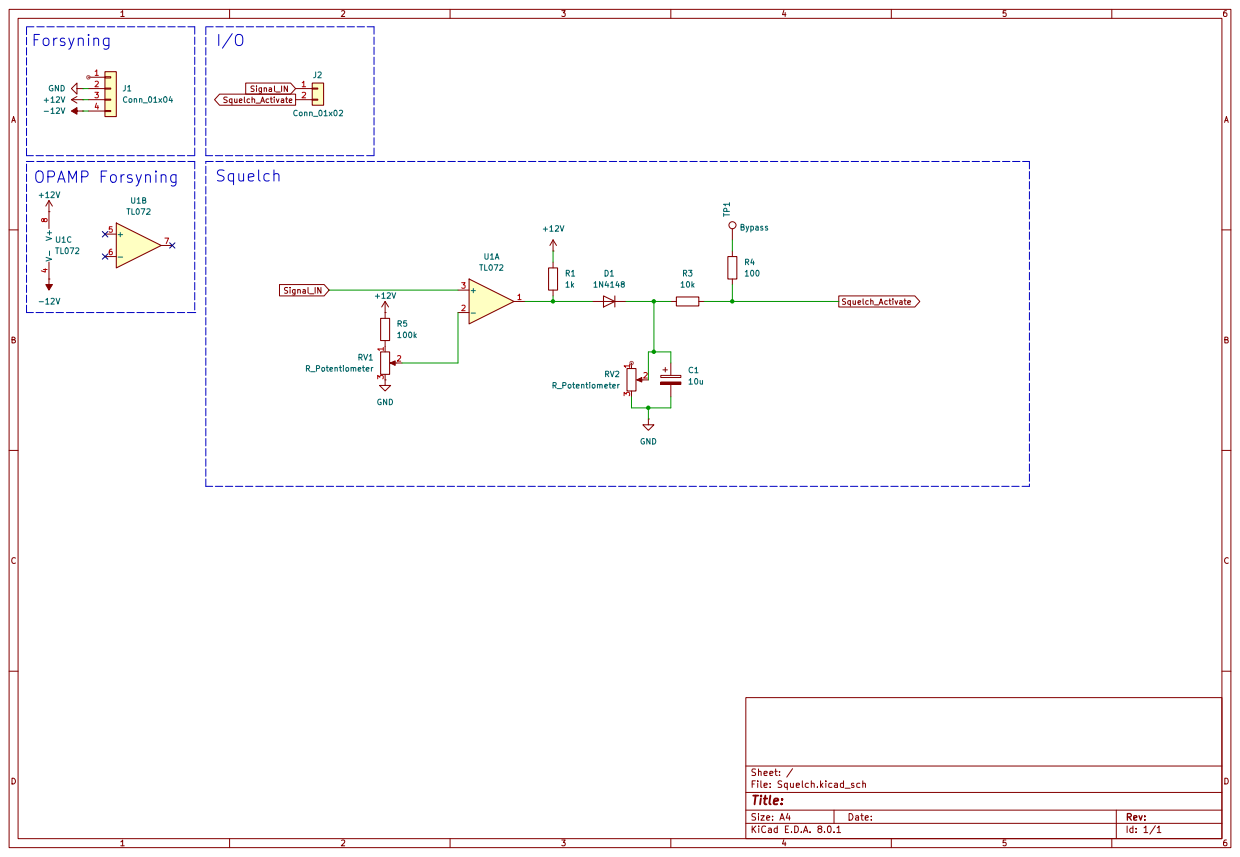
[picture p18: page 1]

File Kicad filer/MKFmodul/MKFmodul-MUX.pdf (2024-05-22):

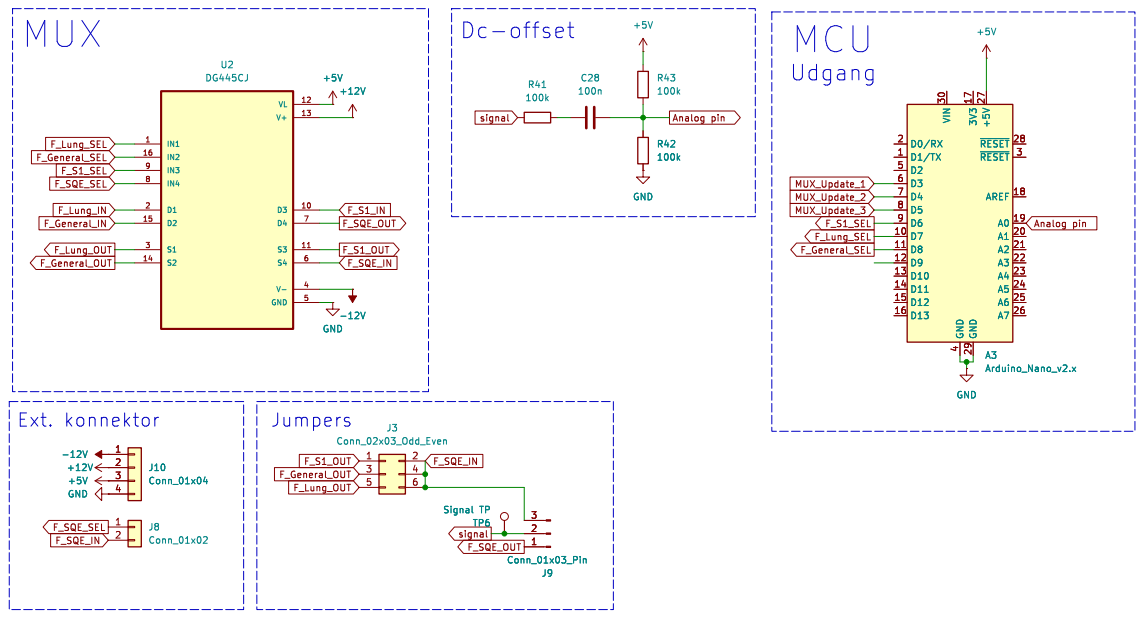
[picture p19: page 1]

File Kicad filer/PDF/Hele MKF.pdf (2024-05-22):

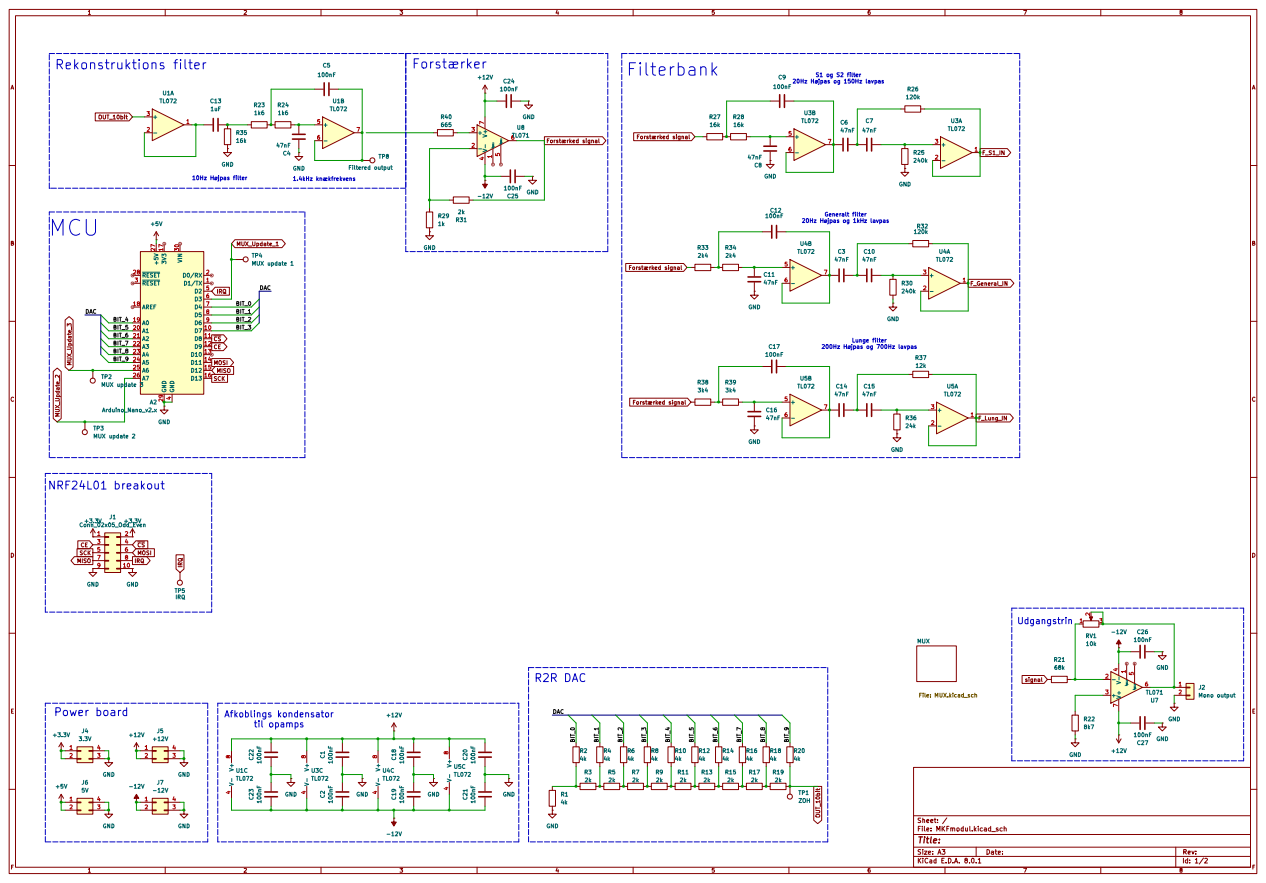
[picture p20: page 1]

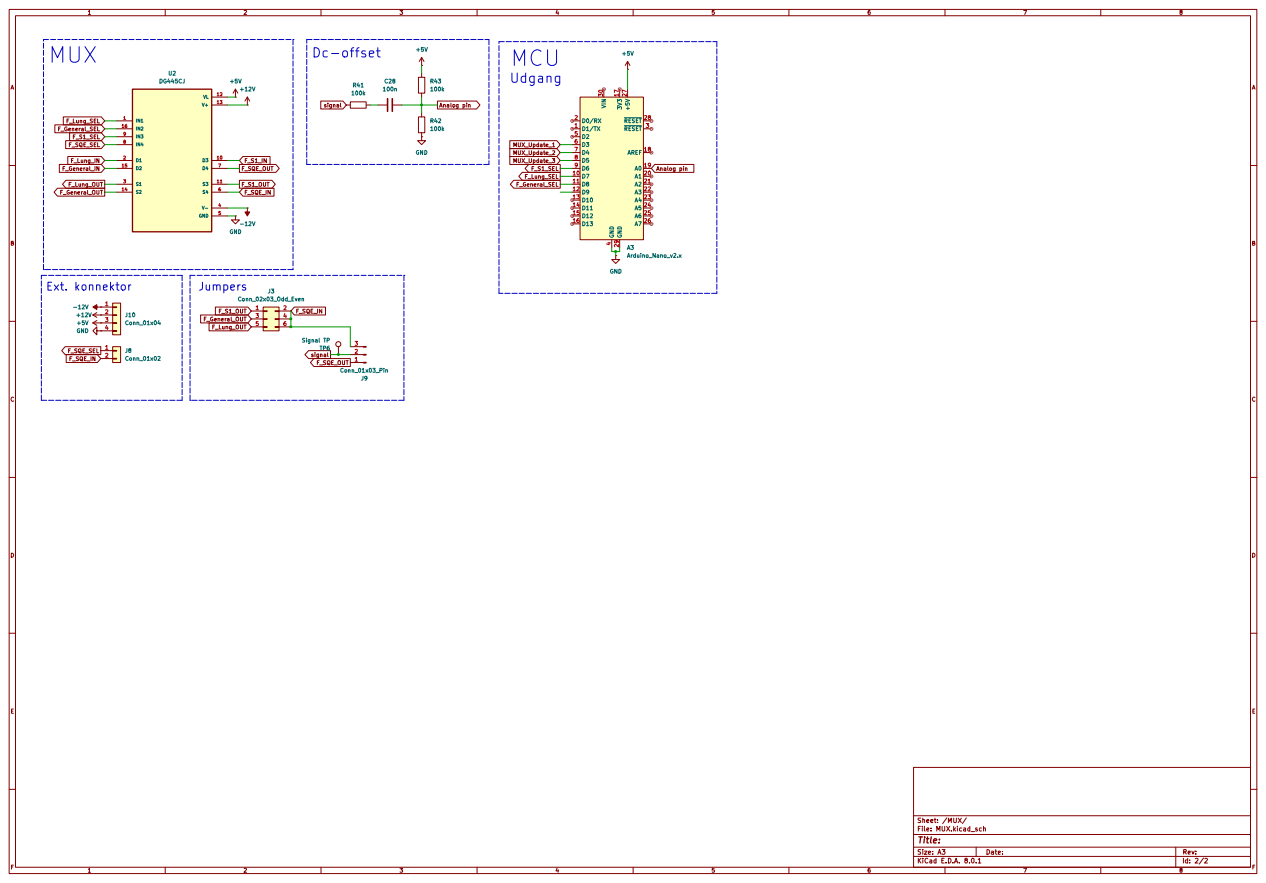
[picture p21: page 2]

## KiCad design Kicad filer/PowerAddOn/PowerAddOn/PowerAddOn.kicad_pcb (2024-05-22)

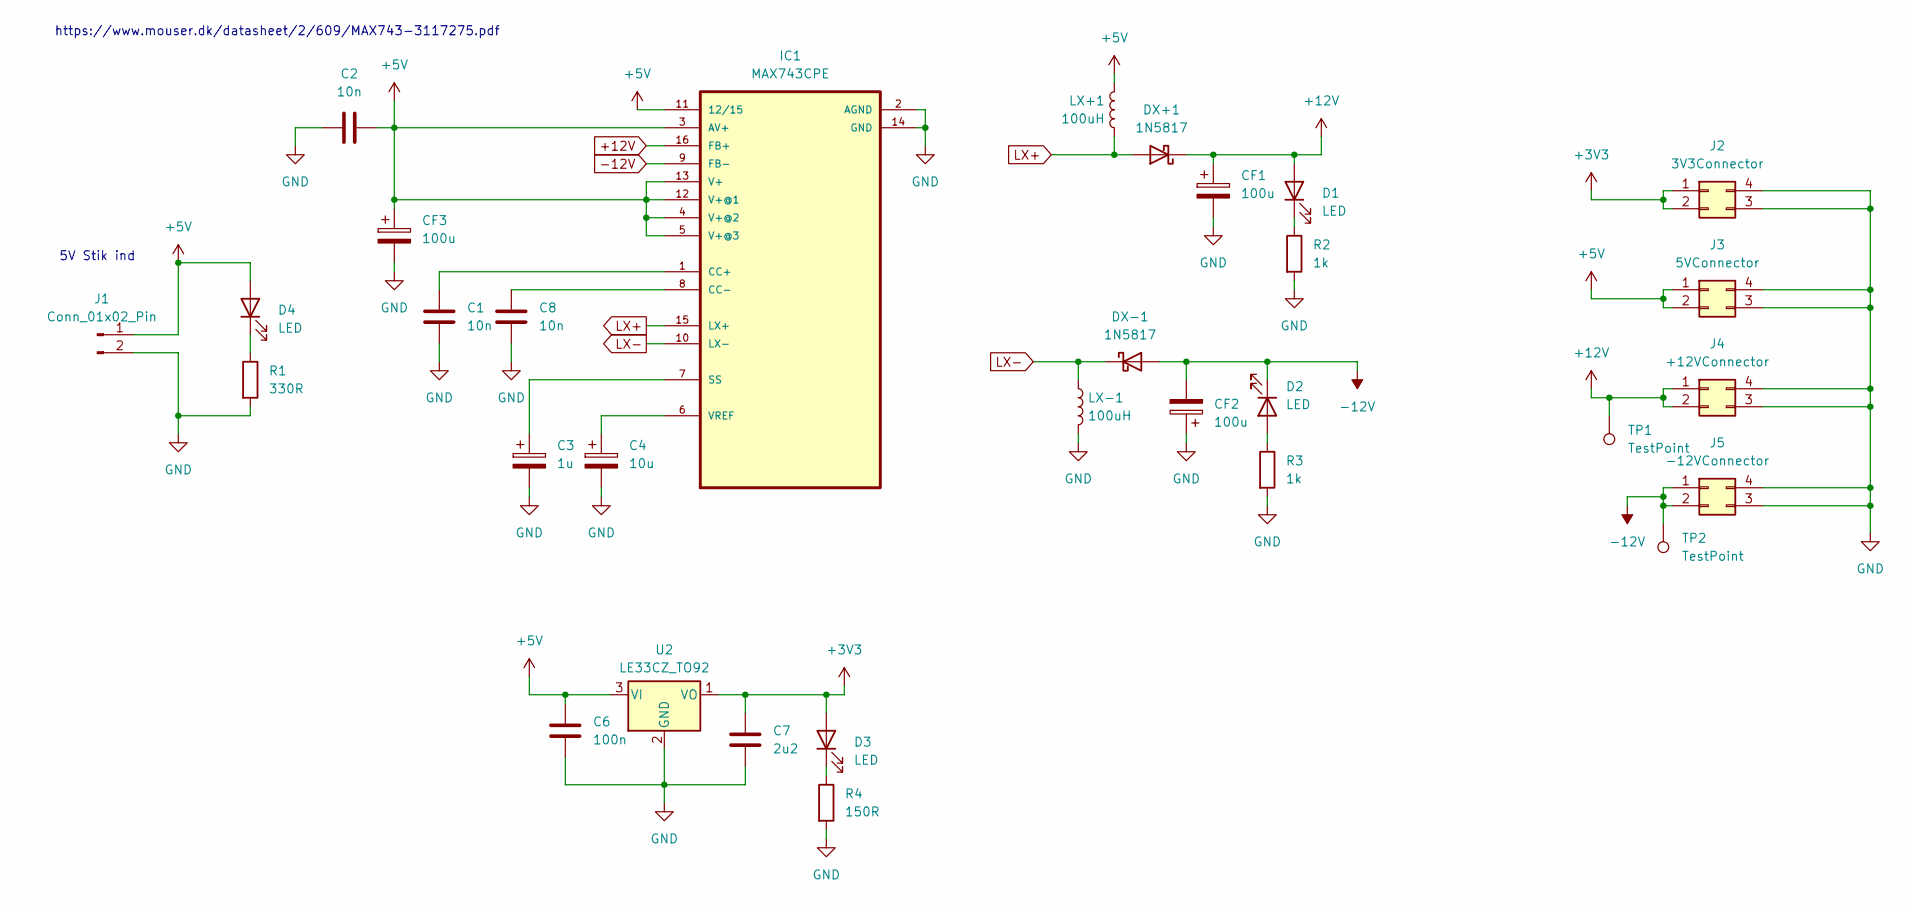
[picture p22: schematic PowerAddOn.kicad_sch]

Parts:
C1, C2, C8: 10n; C_Disc_D4.7mm_W2.5mm_P5.00mm
C3: 1u; CP_Radial_D4.0mm_P2.00mm
C4: 10u; CP_Radial_D4.0mm_P2.00mm
C6: 100n; C_0805_2012Metric_Pad1.18x1.45mm_HandSolder
C7: 2u2; C_0805_2012Metric_Pad1.18x1.45mm_HandSolder
CF1, CF2, CF3: 100u; CP_Axial_L10.0mm_D6.0mm_P15.00mm_Horizontal
D1, D2, D3, D4: LED; LED_D3.0mm
DX+1: 1N5817; D_DO-41_SOD81_P10.16mm_Horizontal
DX-1: 1N5817; D_DO-41_SOD81_P10.16mm_Horizontal
IC1: MAX743CPE; DIP794W47P254L1943H457Q16
J1: Conn_01x02_Pin; PinHeader_1x02_P2.54mm_Vertical
J2: 3V3Connector; PinHeader_2x02_P2.54mm_Vertical
J3: 5VConnector; PinHeader_2x02_P2.54mm_Vertical
J4: +12VConnector; PinHeader_2x02_P2.54mm_Vertical
J5: -12VConnector; PinHeader_2x02_P2.54mm_Vertical
LX+1: 100uH; L_Radial_D10.0mm_P5.00mm_Fastron_07P
LX-1: 100uH; L_Radial_D10.0mm_P5.00mm_Fastron_07P
R1: 330R; R_0805_2012Metric_Pad1.20x1.40mm_HandSolder
R2, R3: 1k; R_0805_2012Metric_Pad1.20x1.40mm_HandSolder
R4: 150R; R_0805_2012Metric_Pad1.20x1.40mm_HandSolder
TP1, TP2: TestPoint; TestPoint_Pad_4.0x4.0mm
U2: LE33CZ_TO92; TO-92_Inline

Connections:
+3V3: C7.1, D3.2 (A), J2.1, J2.2, U2.1 (VO)
+5V: C2.2, C6.1, CF3.1, D4.2 (A), IC1.3 (AV+), IC1.4 (V+@2), IC1.5 (V+@3), IC1.11 (12/15), IC1.12 (V+@1), IC1.13 (V+), J1.1, J3.1, J3.2, LX+1.1, U2.3 (VI)
+12V: CF1.1, D1.2 (A), DX+1.1 (K), IC1.16 (FB+), J4.1, J4.2, TP1.1
-12V: CF2.2, D2.1 (K), DX-1.2 (A), IC1.9 (FB-), J5.1, J5.2, TP2.1
GND: C1.2, C2.1, C3.2, C4.2, C6.2, C7.2, C8.2, CF1.2, CF2.1, CF3.2, IC1.2 (AGND), IC1.14 (GND), J1.2, J2.3, J2.4, J3.3, J3.4, J4.3, J4.4, J5.3, J5.4, LX-1.2, R1.2, R2.2, R3.2, R4.2, U2.2 (GND)
LX+: DX+1.2 (A), IC1.15 (LX+), LX+1.2
LX-: DX-1.1 (K), IC1.10 (LX-), LX-1.1
unnamed: D1.1 (K), R2.1
unnamed: D2.2 (A), R3.1
unnamed: D3.1 (K), R4.1
unnamed: D4.1 (K), R1.1
unnamed: C1.1, IC1.1 (CC+)
unnamed: C8.1, IC1.8 (CC-)
unnamed: C3.1, IC1.7 (SS)
unnamed: C4.1, IC1.6 (VREF)

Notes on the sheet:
5V Stik ind
https://www.mouser.dk/datasheet/2/609/MAX743-3117275.pdf

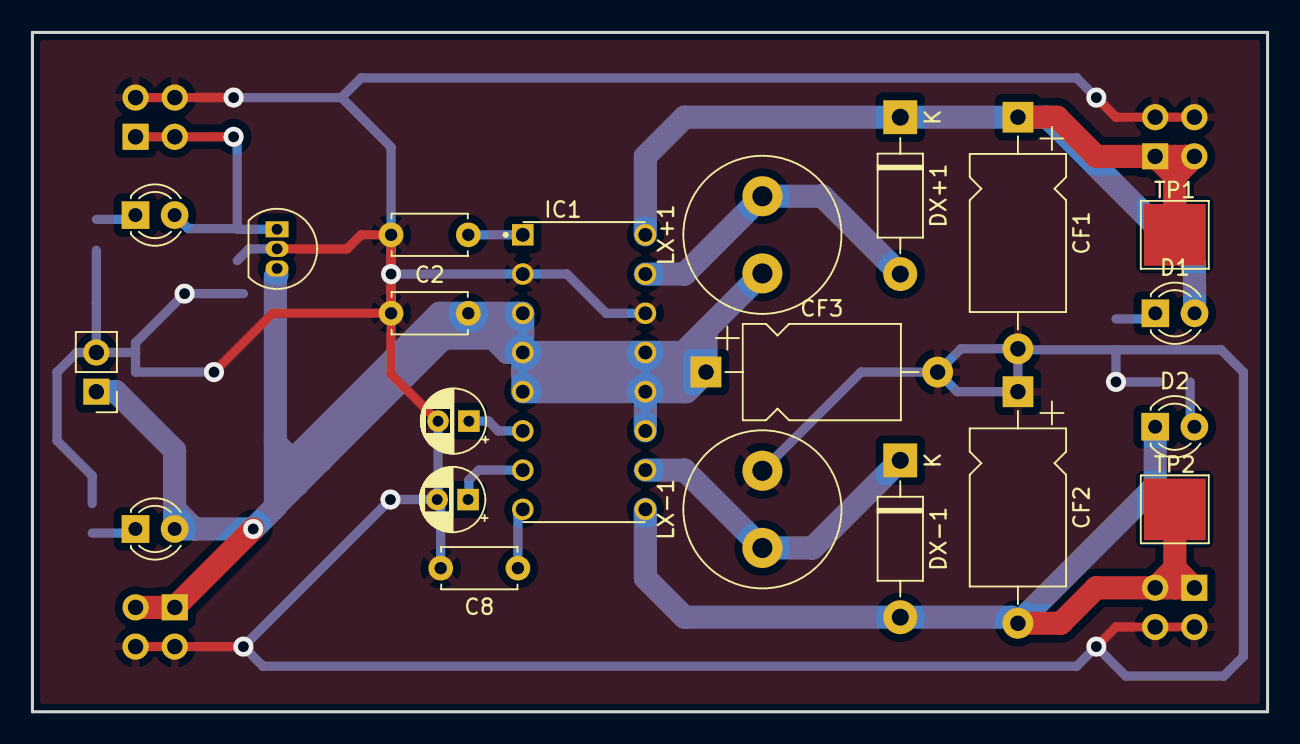
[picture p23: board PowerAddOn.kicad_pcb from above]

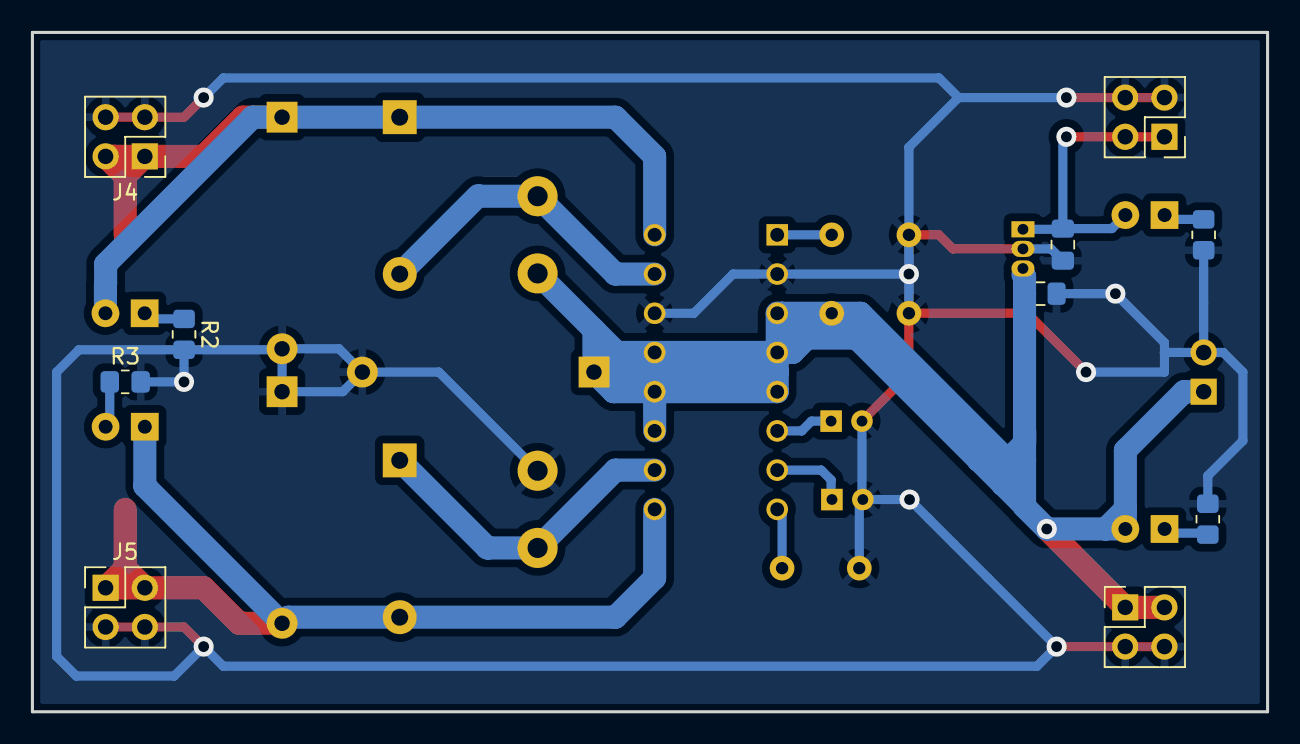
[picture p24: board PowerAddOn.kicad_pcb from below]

Board: 2 copper layers, 80.0 x 44.0 mm, 31 parts (10 on the bottom side), 15 nets.

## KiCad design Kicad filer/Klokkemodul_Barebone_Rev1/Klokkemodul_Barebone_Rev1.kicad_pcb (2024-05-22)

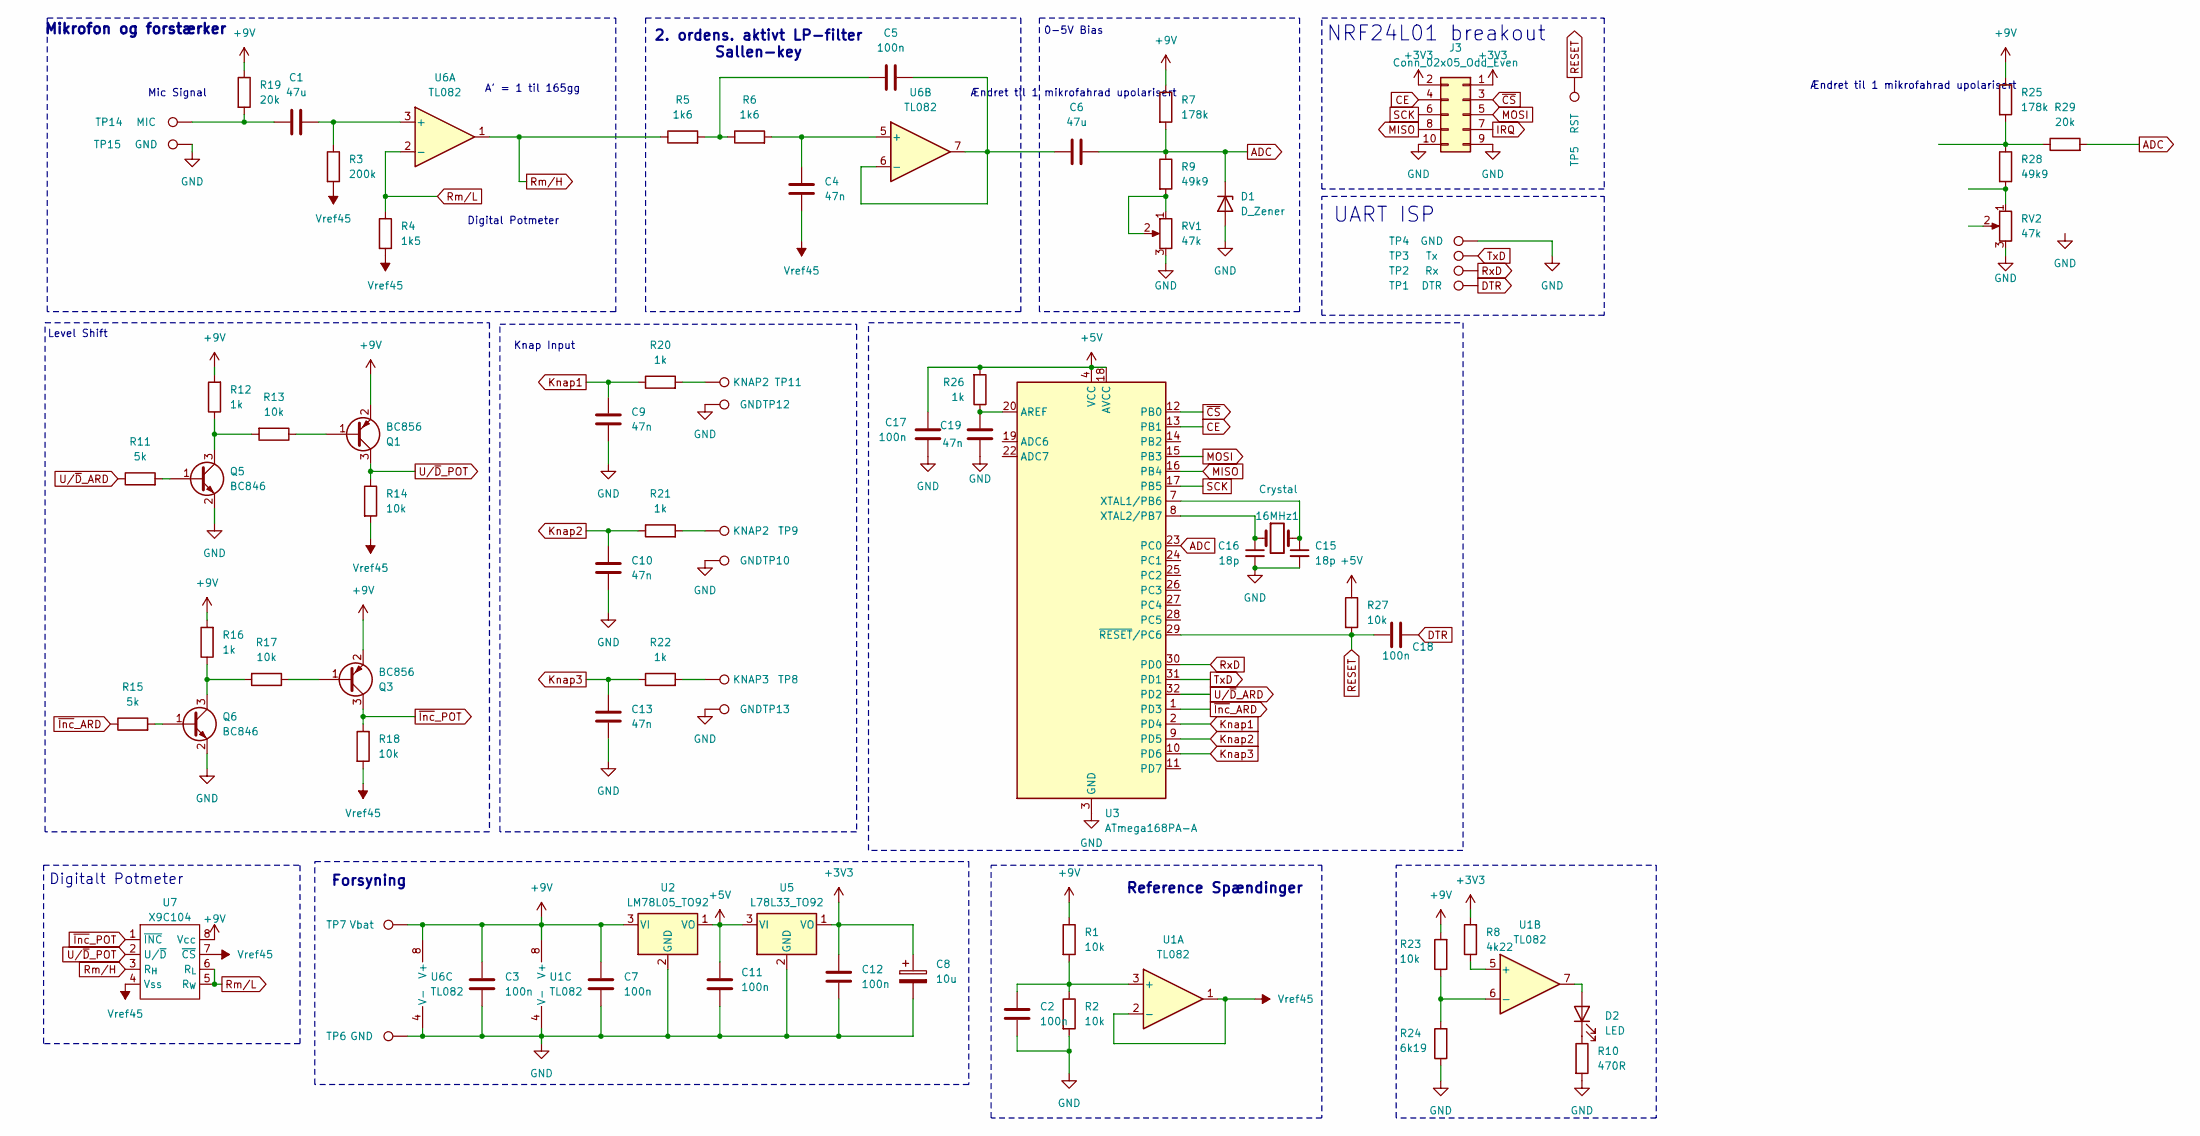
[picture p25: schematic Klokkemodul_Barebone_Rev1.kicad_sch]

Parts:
16MHz1: Crystal; Crystal_HC18-U_Vertical
C1, C6: 47u; CP_Radial_D5.0mm_P2.50mm
C2, C3, C5, C7, C11, C12, C17, C18: 100n; C_0603_1608Metric_Pad1.08x0.95mm_HandSolder
C4, C9, C10, C13, C19: 47n; C_0603_1608Metric_Pad1.08x0.95mm_HandSolder
C8: 10u; CP_Radial_D5.0mm_P2.50mm
C15, C16: 18p; C_0603_1608Metric_Pad1.08x0.95mm_HandSolder
D1: D_Zener; D_DO-15_P10.16mm_Horizontal
D2: LED; LED_D3.0mm
J3: Conn_02x05_Odd_Even; PinSocket_2x05_P2.54mm_Vertical
Q1, Q3: BC856; SOT-23
Q5, Q6: BC846; SOT-23
R1, R2, R13, R14, R17, R18, R23, R27: 10k; R_0603_1608Metric_Pad0.98x0.95mm_HandSolder
R3: 200k; R_0603_1608Metric_Pad0.98x0.95mm_HandSolder
R4: 1k5; R_0603_1608Metric_Pad0.98x0.95mm_HandSolder
R5, R6: 1k6; R_0603_1608Metric_Pad0.98x0.95mm_HandSolder
R7, R25: 178k; R_0603_1608Metric_Pad0.98x0.95mm_HandSolder
R8: 4k22; R_0603_1608Metric_Pad0.98x0.95mm_HandSolder
R9, R28: 49k9; R_0603_1608Metric_Pad0.98x0.95mm_HandSolder
R10: 470R; R_0603_1608Metric_Pad0.98x0.95mm_HandSolder
R11, R15: 5k; R_0603_1608Metric_Pad0.98x0.95mm_HandSolder
R12, R16, R20, R21, R22, R26: 1k; R_0603_1608Metric_Pad0.98x0.95mm_HandSolder
R19, R29: 20k; R_0603_1608Metric_Pad0.98x0.95mm_HandSolder
R24: 6k19; R_0603_1608Metric_Pad0.98x0.95mm_HandSolder
RV1, RV2: 47k; Potentiometer_ACP_CA9-V10_Vertical_Hole
TP1: DTR; TestPoint_Pad_2.5x2.5mm
TP2: Rx; TestPoint_Pad_2.5x2.5mm
TP3: Tx; TestPoint_Pad_2.5x2.5mm
TP4, TP6, TP10, TP12, TP13, TP15: GND; TestPoint_Pad_2.5x2.5mm
TP5: RST; TestPoint_Pad_2.5x2.5mm
TP7: Vbat; TestPoint_Pad_2.5x2.5mm
TP8: KNAP3; TestPoint_Pad_2.5x2.5mm
TP9, TP11: KNAP2; TestPoint_Pad_2.5x2.5mm
TP14: MIC; TestPoint_Pad_2.5x2.5mm
U1, U6: TL082; SOIC-8_3.9x4.9mm_P1.27mm
U2: LM78L05_TO92; TO-92_Inline
U3: ATmega168PA-A; TQFP-32_7x7mm_P0.8mm
U5: L78L33_TO92; TO-92_Inline
U7: X9C104; SOIC-8_3.9x4.9mm_P1.27mm

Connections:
+3V3: C8.1, C12.1, J3.1, J3.2, R8.2, U5.1 (VO)
+5V: C11.1, C17.1, R26.2, R27.1, U2.1 (VO), U3.4 (VCC), U3.6 (VCC), U3.18 (AVCC), U5.3 (VI)
+9V: C3.1, C7.1, Q1.2 (E), Q3.2 (E), R1.1, R7.1, R12.2, R16.2, R19.1, R23.2, R25.1, TP7.1, U1.8 (V+), U2.3 (VI), U6.8 (V+), U7.8 (Vcc); also elsewhere on the board
ADC: C6.2, D1.1 (K), R7.2, R9.1, R29.2, U3.23 (PC0)
CE: J3.4, U3.13 (PB1)
DTR: C18.1, TP1.1
GND: C2.2, C3.2, C7.2, C8.2, C9.2, C10.2, C11.2, C12.2, C13.2, C15.2, C16.2, C17.2, C19.2, D1.2 (A), J3.9, J3.10, Q5.2 (E), Q6.2 (E), R2.2, R10.2, R24.1, RV1.3, RV2.3, TP4.1, TP6.1, TP10.1, TP12.1, TP13.1, TP15.1, U1.4 (V-), U2.2 (GND), U3.3 (GND), U3.5 (GND), U3.21 (GND), U5.2 (GND), U6.4 (V-)
IRQ: J3.7
Knap1: C9.1, R20.1, U3.2 (PD4)
Knap2: C10.1, R21.1, U3.9 (PD5)
Knap3: C13.1, R22.1, U3.10 (PD6)
MISO: J3.8, U3.16 (PB4)
MOSI: J3.5, U3.15 (PB3)
unnamed: C1.1, R19.2, TP14.1
unnamed: C5.1, R5.2, R6.1
unnamed: D2.2 (A), U1.7
unnamed: D2.1 (K), R10.1
unnamed 17: Q1.1 (B), R13.1; also elsewhere on the board
unnamed 18: Q3.1 (B), R17.1; also elsewhere on the board
unnamed: Q5.1 (B), R11.2
unnamed: Q5.3 (C), R12.1, R13.2
unnamed: Q6.1 (B), R15.2
unnamed: Q6.3 (C), R16.1, R17.2
unnamed: R9.2, RV1.1, RV1.2
unnamed: R20.2, TP11.1
unnamed: R21.2, TP9.1
unnamed: R22.2, TP8.1
unnamed: R25.2, R28.1, R29.1
unnamed: R28.2, RV2.1
unnamed: C2.1, R1.2, R2.1, U1.3 (+)
unnamed: R8.1, U1.5 (+)
unnamed: R23.1, R24.2, U1.6 (-)
unnamed: C19.1, R26.1, U3.20 (AREF)
unnamed: 16MHz1.2, C15.1, U3.7 (XTAL1/PB6)
unnamed: 16MHz1.1, C16.1, U3.8 (XTAL2/PB7)
unnamed: C1.2, R3.1, U6.3 (+)
unnamed: C4.1, R6.2, U6.5 (+)
unnamed: C5.2, C6.1, U6.6 (-), U6.7
RESET: C18.2, R27.2, TP5.1, U3.29 (~RESET/PC6)
Rm/H: R5.1, U6.1, U7.3 (R_{H})
Rm/L: R4.1, U6.2 (-), U7.5 (R_{W}), U7.6 (R_{L})
RxD: TP2.1, U3.30 (PD0)
SCK: J3.6, U3.17 (PB5)
TxD: TP3.1, U3.31 (PD1)
U/~D_ARD: R11.1, U3.32 (PD2)
U/~D_POT: Q1.3 (C), R14.1, U7.2 (U/~D); also elsewhere on the board
Vref45: C4.2, R3.2, R4.2, R14.2, R18.2, U1.1, U1.2 (-), U7.4 (Vss), U7.7 (~CS)
~CS: J3.3, U3.12 (PB0)
~Inc_ARD: R15.1, U3.1 (PD3)
~Inc_POT: Q3.3 (C), R18.1, U7.1 (~INC); also elsewhere on the board

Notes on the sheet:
Digitalt Potmeter
Digital Potmeter
2. ordens. aktivt LP-filter Sallen-key
A' = 1 til 165gg
0-5V Bias
Ændret til 1 mikrofahrad upolarisert
NRF24L01 breakout
Mic Signal
Knap Input
Forsyning
UART ISP
Level Shift
Reference Spændinger
Mikrofon og forstærker

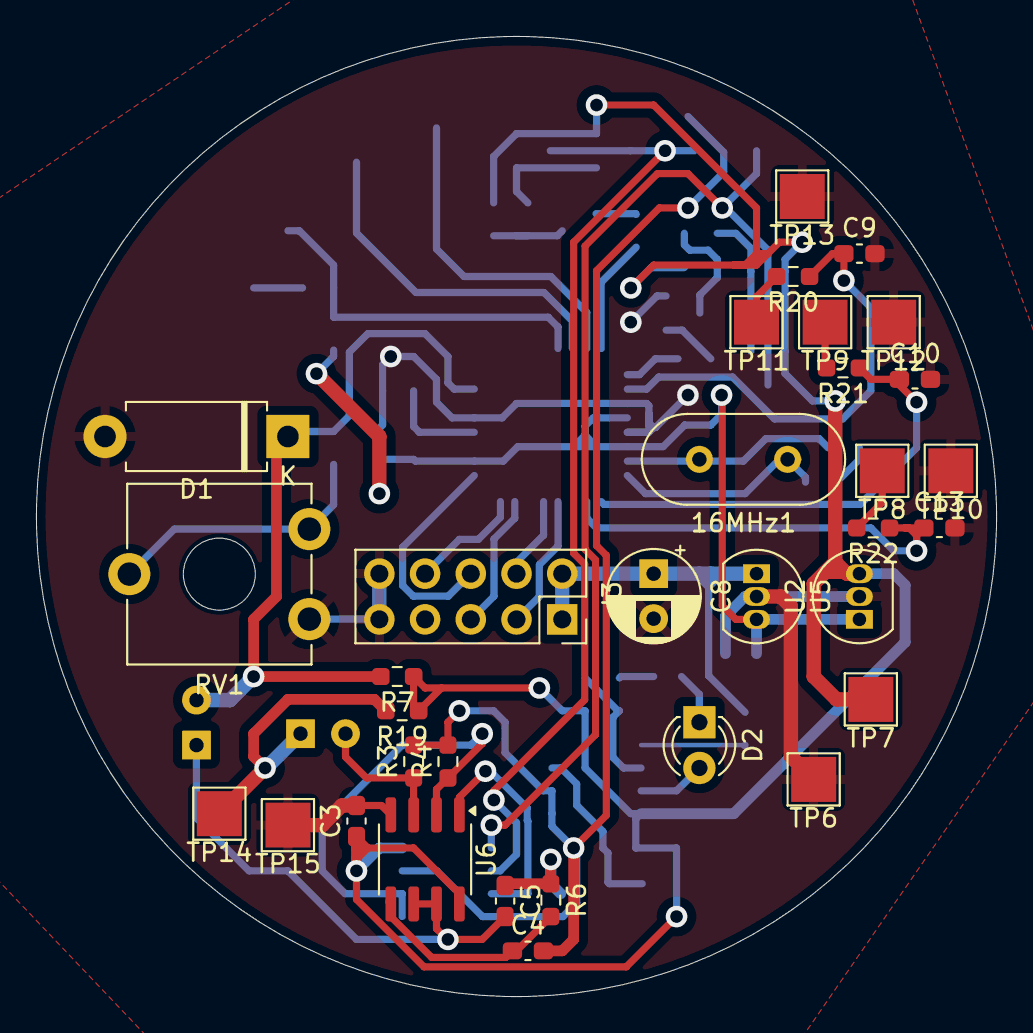
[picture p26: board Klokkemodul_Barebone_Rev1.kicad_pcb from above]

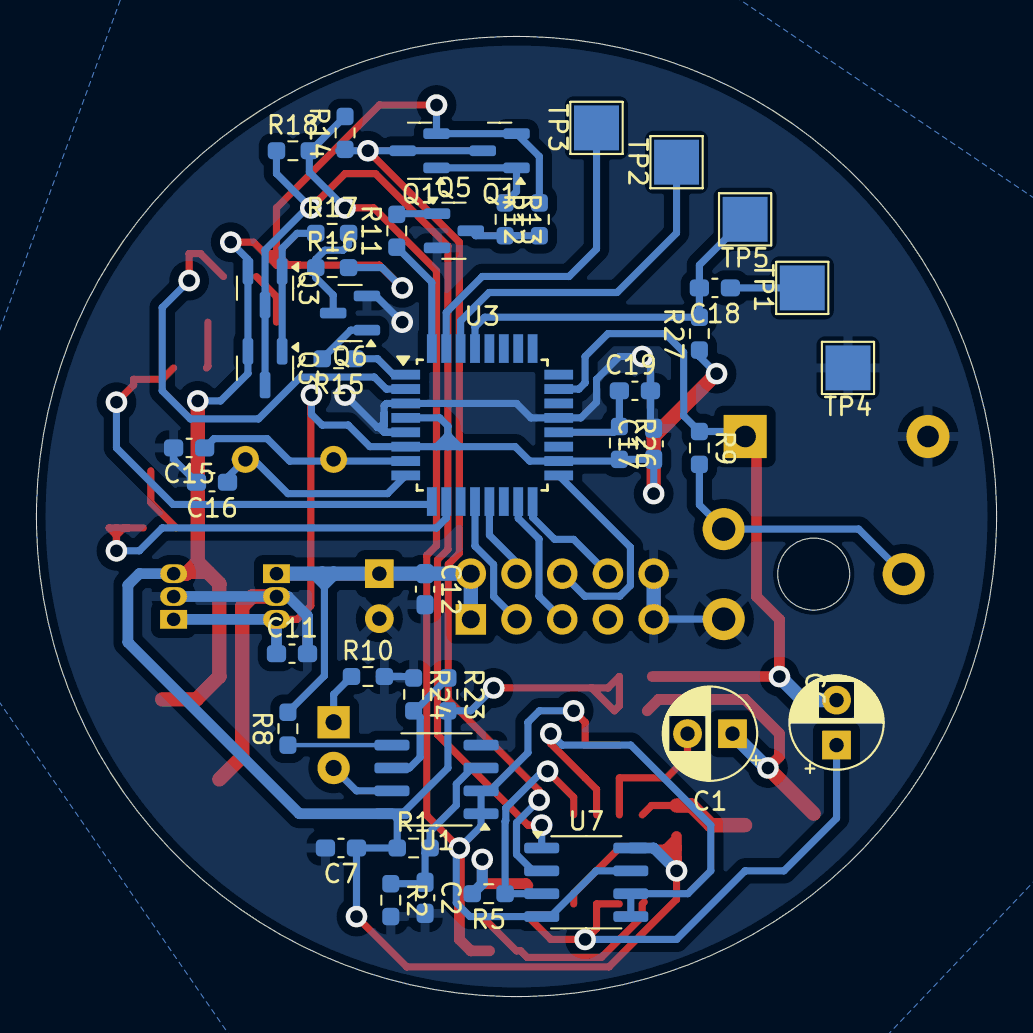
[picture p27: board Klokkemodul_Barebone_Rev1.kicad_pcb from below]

Board: 2 copper layers, 53.3 x 53.3 mm, 76 parts (43 on the bottom side), 47 nets.

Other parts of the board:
Q1#2, Q3#2: BC856; SOT-23

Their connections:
+9V: Q1#2.2 (E), Q3#2.2 (E); also elsewhere on the board
unnamed 17: Q1#2.1 (B); also elsewhere on the board
unnamed 18: Q3#2.1 (B); also elsewhere on the board
U/~D_POT: Q1#2.3 (C); also elsewhere on the board
~Inc_POT: Q3#2.3 (C); also elsewhere on the board

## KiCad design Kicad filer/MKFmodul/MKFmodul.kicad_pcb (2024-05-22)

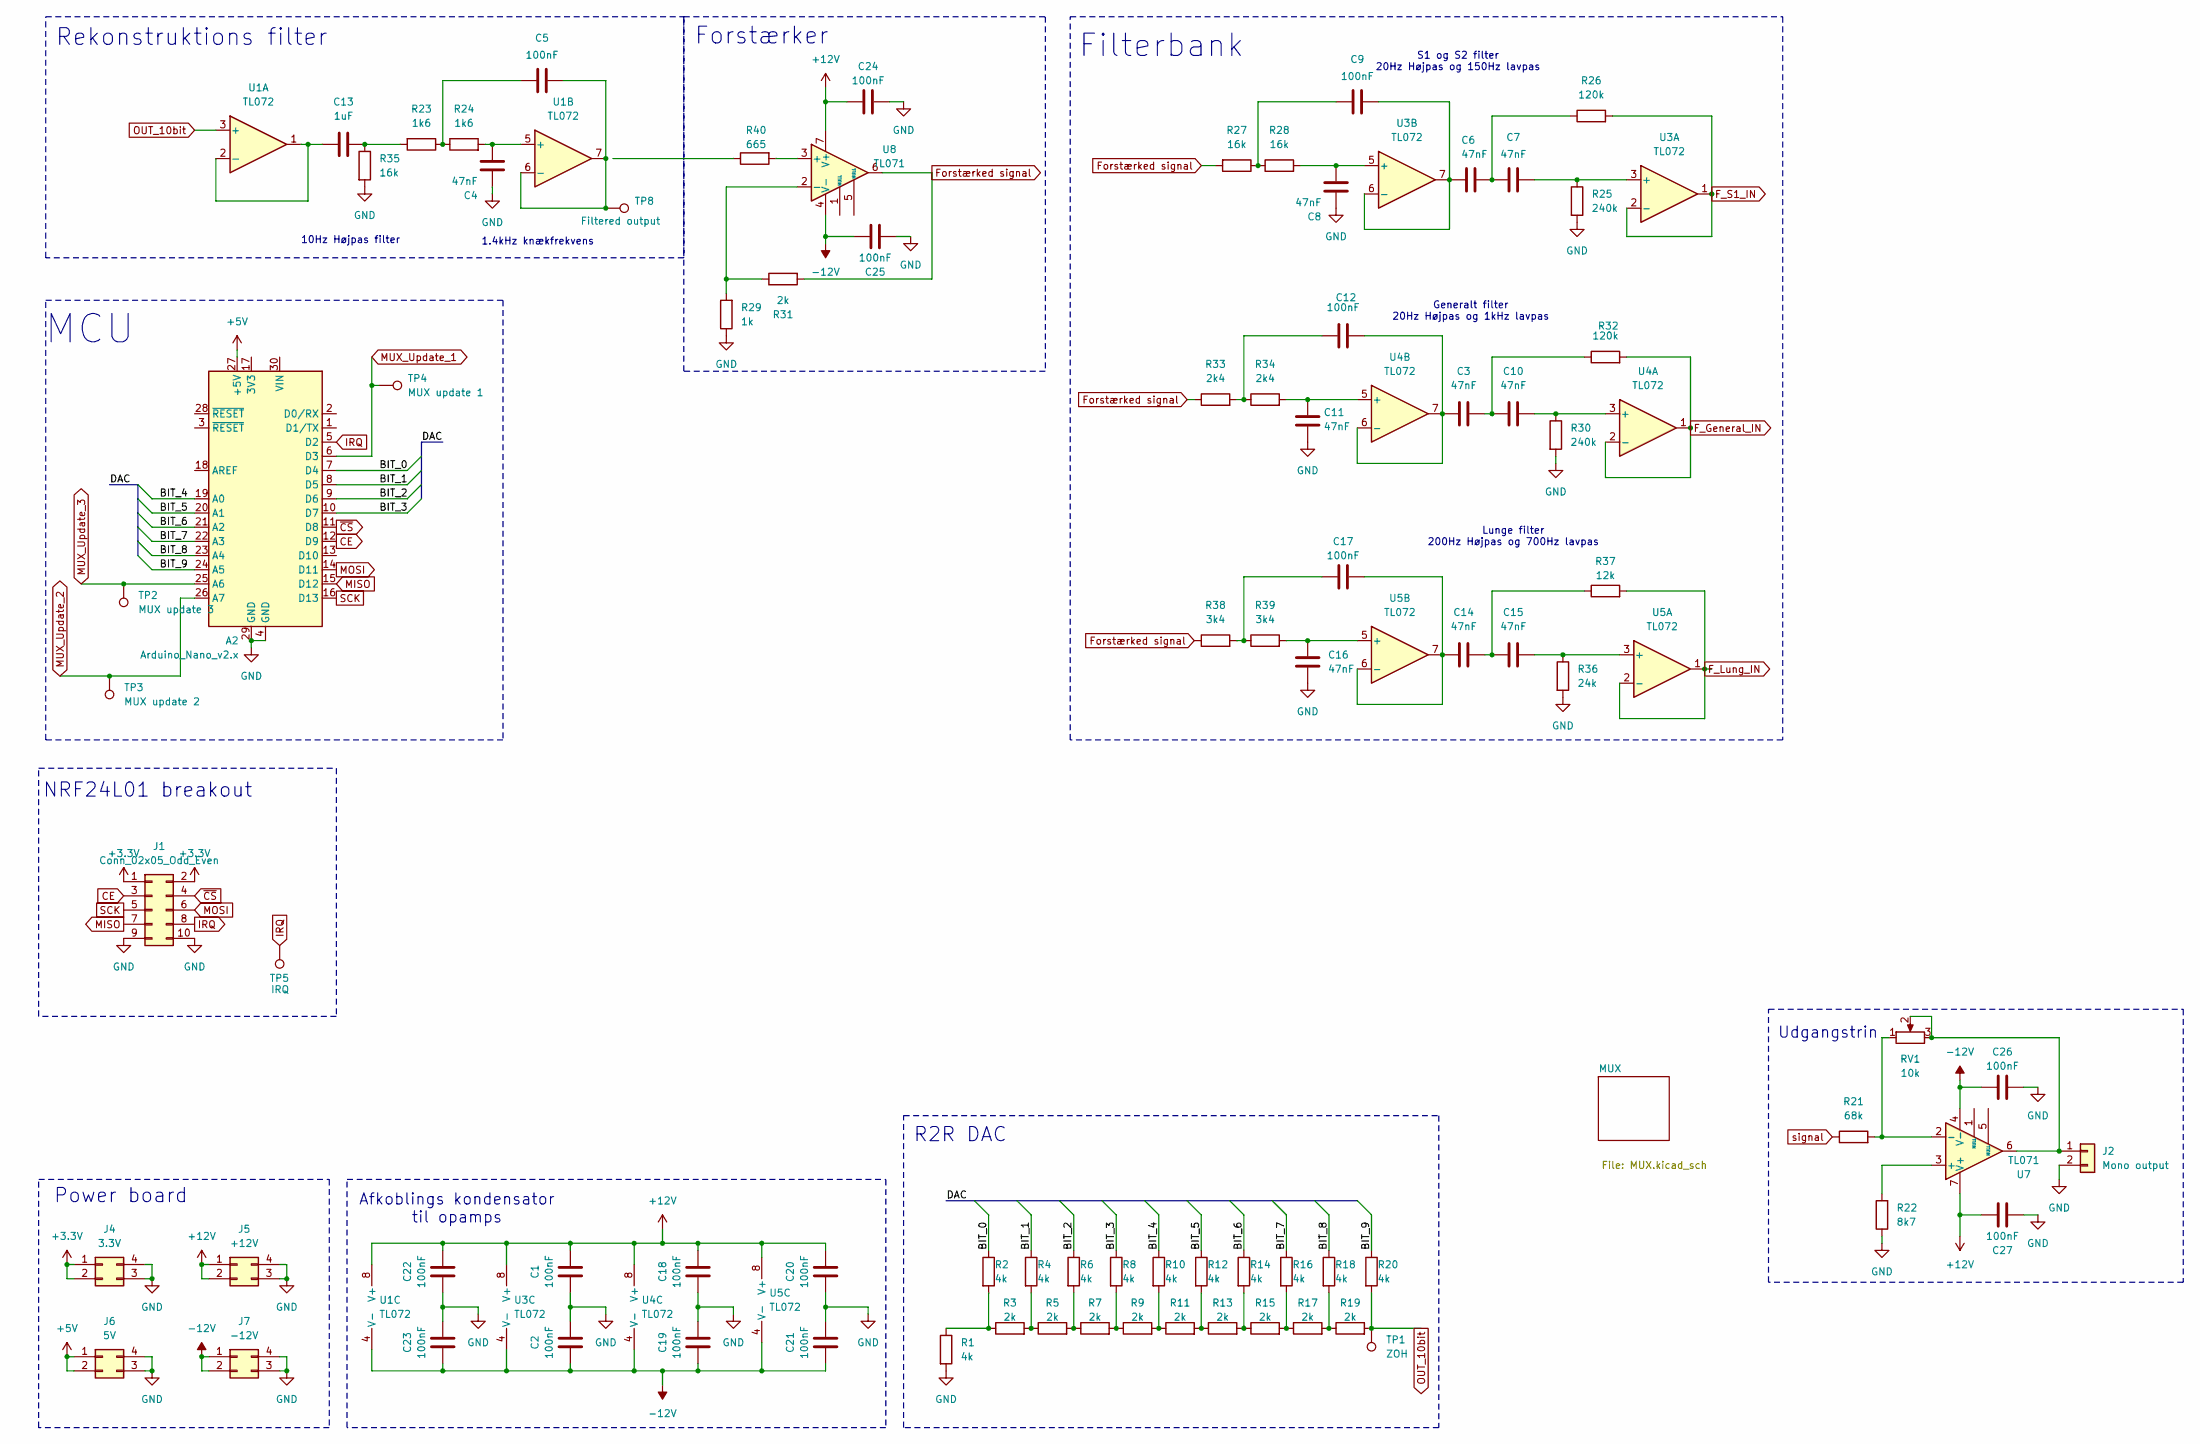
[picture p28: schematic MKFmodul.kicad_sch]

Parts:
A2: Arduino_Nano_v2.x; Arduino_Nano
C1, C2, C5, C9, C12, C17, C18, C19, C20, C21, C22, C23, C24, C25, C26, C27: 100nF; C_Disc_D7.0mm_W2.5mm_P5.00mm
C3, C4, C6, C7, C8, C10, C11, C14, C15, C16: 47nF; C_Disc_D7.0mm_W2.5mm_P5.00mm
C13: 1uF; C_Disc_D7.0mm_W2.5mm_P5.00mm
J1: Conn_02x05_Odd_Even; PinSocket_2x05_P2.54mm_Vertical
J2: Mono output; PinHeader_1x02_P2.54mm_Vertical
J4: 3.3V; PinHeader_2x02_P2.54mm_Vertical
J5: +12V; PinHeader_2x02_P2.54mm_Vertical
J6: 5V; PinHeader_2x02_P2.54mm_Vertical
J7: -12V; PinHeader_2x02_P2.54mm_Vertical
R1, R2, R4, R6, R8, R10, R12, R14, R16, R18, R20: 4k; R_Axial_DIN0207_L6.3mm_D2.5mm_P10.16mm_Horizontal
R3, R5, R7, R9, R11, R13, R15, R17, R19, R31: 2k; R_Axial_DIN0207_L6.3mm_D2.5mm_P10.16mm_Horizontal
R21: 68k; R_Axial_DIN0207_L6.3mm_D2.5mm_P10.16mm_Horizontal
R22: 8k7; R_Axial_DIN0207_L6.3mm_D2.5mm_P10.16mm_Horizontal
R23, R24: 1k6; R_Axial_DIN0207_L6.3mm_D2.5mm_P10.16mm_Horizontal
R25, R30: 240k; R_Axial_DIN0207_L6.3mm_D2.5mm_P10.16mm_Horizontal
R26, R32: 120k; R_Axial_DIN0207_L6.3mm_D2.5mm_P10.16mm_Horizontal
R27, R28, R35: 16k; R_Axial_DIN0207_L6.3mm_D2.5mm_P10.16mm_Horizontal
R29: 1k; R_Axial_DIN0207_L6.3mm_D2.5mm_P10.16mm_Horizontal
R33, R34: 2k4; R_Axial_DIN0207_L6.3mm_D2.5mm_P10.16mm_Horizontal
R36: 24k; R_Axial_DIN0207_L6.3mm_D2.5mm_P10.16mm_Horizontal
R37: 12k; R_Axial_DIN0207_L6.3mm_D2.5mm_P10.16mm_Horizontal
R38, R39: 3k4; R_Axial_DIN0207_L6.3mm_D2.5mm_P10.16mm_Horizontal
R40: 665; R_Axial_DIN0207_L6.3mm_D2.5mm_P10.16mm_Horizontal
RV1: 10k; PinHeader_1x03_P2.54mm_Vertical
TP1: ZOH; TestPoint_Pad_3.0x3.0mm
TP2: MUX update 3; TestPoint_Pad_3.0x3.0mm
TP3: MUX update 2; TestPoint_Pad_3.0x3.0mm
TP4: MUX update 1; TestPoint_Pad_3.0x3.0mm
TP5: IRQ; PinHeader_1x01_P2.54mm_Vertical
TP8: Filtered output; PinHeader_1x01_P2.54mm_Vertical
U1, U3, U4, U5: TL072; DIP-8_W7.62mm_LongPads
U7, U8: TL071; DIP-8_W7.62mm_LongPads

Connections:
+3.3V: J1.1, J1.2, J4.1, J4.2
+5V: A2.27 (+5V), J6.1, J6.2; also elsewhere on the board
+12V: C1.2, C18.2, C20.2, C22.2, C24.1, C27.1, J5.1, J5.2, U1.8 (V+), U3.8 (V+), U4.8 (V+), U5.8 (V+), U7.7 (V+), U8.7 (V+); also elsewhere on the board
-12V: C2.1, C19.1, C21.1, C23.1, C25.1, C26.2, J7.1, J7.2, U1.4 (V-), U3.4 (V-), U4.4 (V-), U5.4 (V-), U7.4 (V-), U8.4 (V-); also elsewhere on the board
/BIT_0: A2.7 (D4), R2.1
/BIT_1: A2.8 (D5), R4.1
/BIT_2: A2.9 (D6), R6.1
/BIT_3: A2.10 (D7), R8.1
/BIT_4: A2.19 (A0), R10.1
/BIT_5: A2.20 (A1), R12.1
/BIT_6: A2.21 (A2), R14.1
/BIT_7: A2.22 (A3), R16.1
/BIT_8: A2.23 (A4), R18.1
/BIT_9: A2.24 (A5), R20.1
Amp_signal: R27.2, R31.2, R33.1, R38.1, U8.6
CE: A2.12 (D9), J1.3
F_General_IN: R32.2, U4.1, U4.2 (-); also elsewhere on the board
F_Lung_IN: R37.2, U5.1, U5.2 (-); also elsewhere on the board
F_S1_IN: R26.2, U3.1, U3.2 (-); also elsewhere on the board
GND: A2.4 (GND), A2.29 (GND), C1.1, C2.2, C4.1, C8.1, C11.2, C16.2, C18.1, C19.2, C20.1, C21.2, C22.1, C23.2, C24.2, C25.2, C26.1, C27.2, J1.9, J1.10, J2.2, J4.3, J4.4, J5.3, J5.4, J6.3, J6.4, J7.3, J7.4, R1.2, R22.1, R25.2, R29.1, R30.2, R35.2, R36.2; also elsewhere on the board
IRQ: A2.5 (D2), J1.8, TP5.1
MISO: A2.15 (D12), J1.7
MOSI: A2.14 (D11), J1.6
MUX_Update_1: A2.6 (D3), TP4.1; also elsewhere on the board
MUX_Update_2: A2.26 (A7), TP3.1; also elsewhere on the board
MUX_Update_3: A2.25 (A6), TP2.1; also elsewhere on the board
unnamed: C5.1, R23.1, R24.1
unnamed: C6.1, C7.2, R26.1
unnamed: C9.1, R27.1, R28.1
unnamed: C3.2, C10.1, R32.1
unnamed: C12.1, R33.2, R34.1
unnamed: C13.2, R23.2, R35.1
unnamed: C14.2, C15.1, R37.1
unnamed: C17.1, R38.2, R39.1
unnamed: J2.1, RV1.2, RV1.3, U7.6
unnamed: R1.1, R2.2, R3.1
unnamed: R3.2, R4.2, R5.1
unnamed: R5.2, R6.2, R7.1
unnamed: R7.2, R8.2, R9.1
unnamed: R9.2, R10.2, R11.1
unnamed: R11.2, R12.2, R13.1
unnamed: R13.2, R14.2, R15.1
unnamed: R15.2, R16.2, R17.1
unnamed: R17.2, R18.2, R19.1
unnamed: C13.1, U1.1, U1.2 (-)
unnamed: C4.2, R24.2, U1.5 (+)
unnamed: C5.2, TP8.1, U1.6 (-), U1.7
unnamed: C7.1, R25.1, U3.3 (+)
unnamed: C8.2, R28.2, U3.5 (+)
unnamed: C6.2, C9.2, U3.6 (-), U3.7
unnamed: C10.2, R30.1, U4.3 (+)
unnamed: C11.1, R34.2, U4.5 (+)
unnamed: C3.1, C12.2, U4.6 (-), U4.7
unnamed: C15.2, R36.1, U5.3 (+)
unnamed: C16.1, R39.2, U5.5 (+)
unnamed: C14.1, C17.2, U5.6 (-), U5.7
unnamed: R22.2, U7.3 (+)
unnamed: R21.2, RV1.1, U7.2 (-)
unnamed: R40.2, U8.3 (+)
unnamed: R29.2, R31.1, U8.2 (-)
OUT_10bit: R19.2, R20.2, TP1.1, U1.3 (+)
SCK: A2.16 (D13), J1.5
signal: R21.1; also elsewhere on the board
~CS: A2.11 (D8), J1.4

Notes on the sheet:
1.4kHz knækfrekvens
S1 og S2 filter 20Hz Højpas og 150Hz lavpas
MCU
10Hz Højpas filter
Forstærker
Rekonstruktions filter
Power board
Generalt filter 20Hz Højpas og 1kHz lavpas
R2R DAC
NRF24L01 breakout
Lunge filter 200Hz Højpas og 700Hz lavpas
Udgangstrin
Filterbank
Afkoblings kondensator til opamps

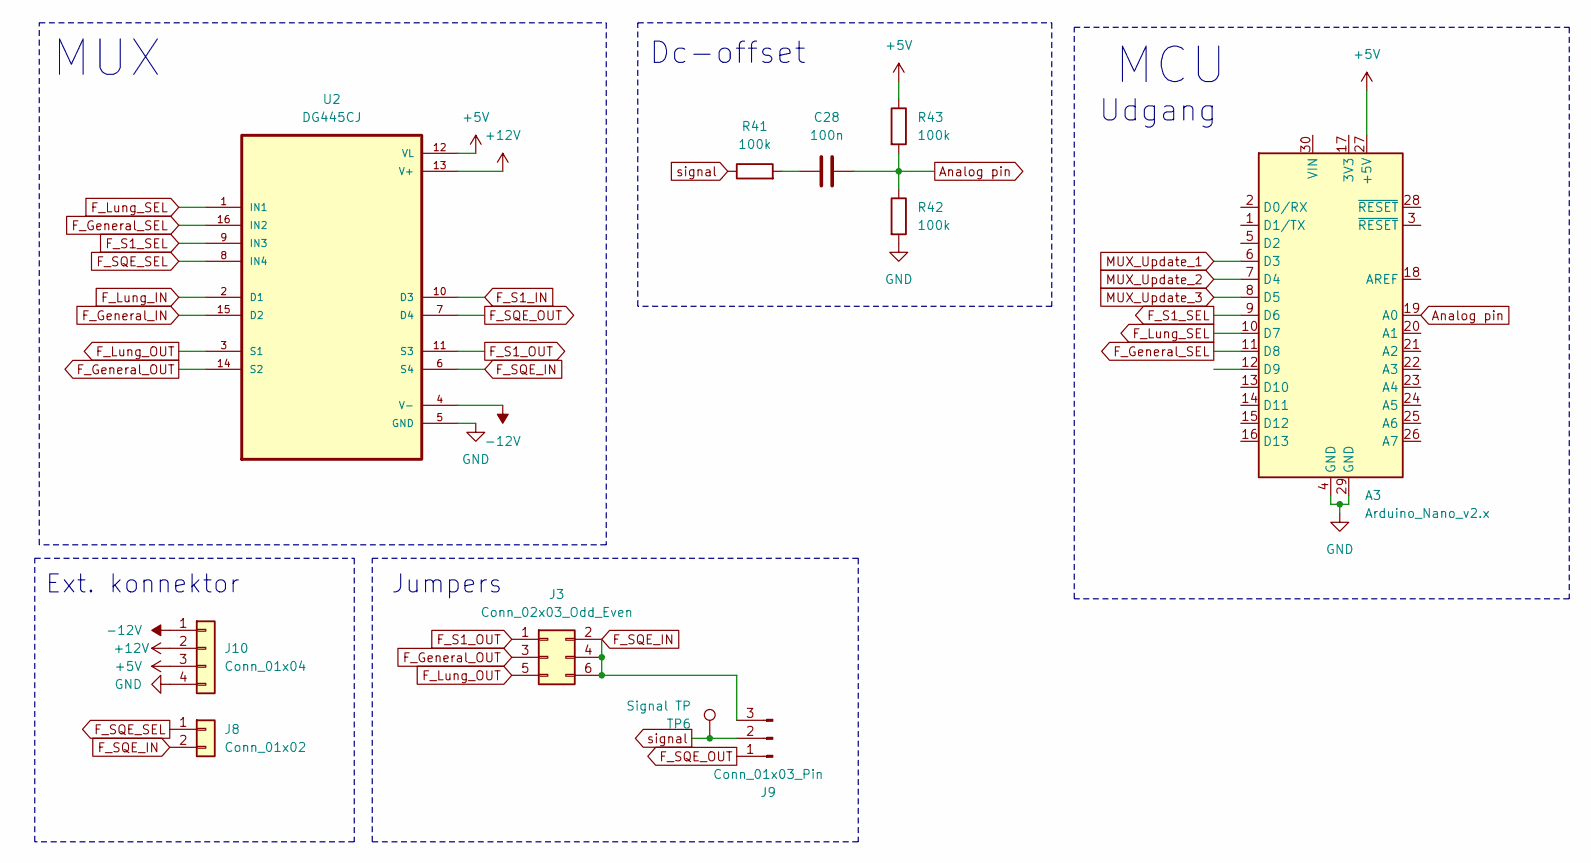
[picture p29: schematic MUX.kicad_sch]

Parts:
A3: Arduino_Nano_v2.x; Arduino_Nano
C28: 100n; C_Disc_D7.0mm_W2.5mm_P5.00mm
J3: Conn_02x03_Odd_Even; PinHeader_2x03_P2.54mm_Vertical
J8: Conn_01x02; PinHeader_1x02_P2.54mm_Vertical
J9: Conn_01x03_Pin; PinHeader_1x03_P2.54mm_Vertical
J10: Conn_01x04; PinHeader_1x04_P2.54mm_Vertical
R41, R42, R43: 100k; R_Axial_DIN0207_L6.3mm_D2.5mm_P10.16mm_Horizontal
TP6: Signal TP; PinHeader_1x01_P2.54mm_Vertical
U2: DG445CJ; DIP794W47P254L1943H457Q16

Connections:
+5V: A3.27 (+5V), J10.3, R43.1, U2.12 (VL); also elsewhere on the board
+12V: J10.2, U2.13 (V+); also elsewhere on the board
-12V: J10.1, U2.4 (V-); also elsewhere on the board
Analog pin: A3.19 (A0), C28.2, R42.1, R43.2
F_General_IN: U2.15 (D2); also elsewhere on the board
F_General_OUT: J3.3, U2.14 (S2)
F_General_SEL: A3.11 (D8), U2.16 (IN2)
F_Lung_IN: U2.2 (D1); also elsewhere on the board
F_Lung_OUT: J3.5, U2.3 (S1)
F_Lung_SEL: A3.10 (D7), U2.1 (IN1)
F_S1_IN: U2.10 (D3); also elsewhere on the board
F_S1_OUT: J3.1, U2.11 (S3)
F_S1_SEL: A3.9 (D6), U2.9 (IN3)
F_SQE_IN: J3.2, J3.4, J3.6, J8.2, J9.3, U2.6 (S4)
F_SQE_OUT: J9.1, U2.7 (D4)
F_SQE_SEL: J8.1, U2.8 (IN4)
GND: A3.4 (GND), A3.29 (GND), J10.4, R42.2, U2.5 (GND); also elsewhere on the board
MUX_Update_1: A3.6 (D3); also elsewhere on the board
MUX_Update_2: A3.7 (D4); also elsewhere on the board
MUX_Update_3: A3.8 (D5); also elsewhere on the board
unnamed: C28.1, R41.2
signal: J9.2, R41.1, TP6.1; also elsewhere on the board

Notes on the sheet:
Jumpers
MUX
Udgang
Dc-offset
Ext. konnektor
MCU

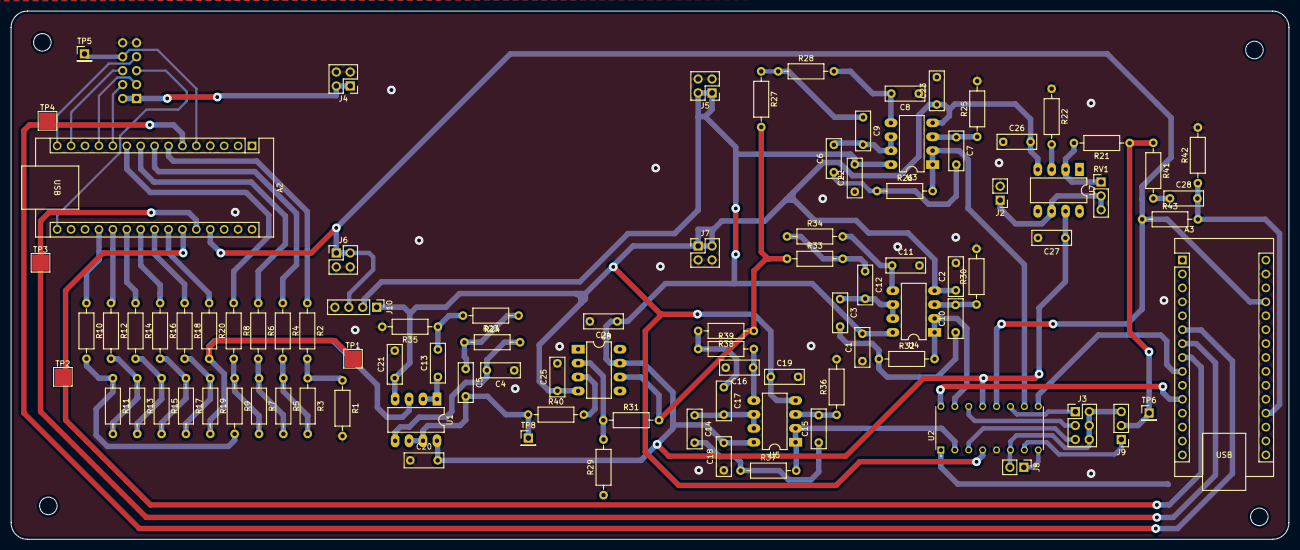
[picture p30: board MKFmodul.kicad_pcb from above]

Board: 2 copper layers, 233.2 x 96.4 mm, 98 parts (1 on the bottom side), 75 nets.

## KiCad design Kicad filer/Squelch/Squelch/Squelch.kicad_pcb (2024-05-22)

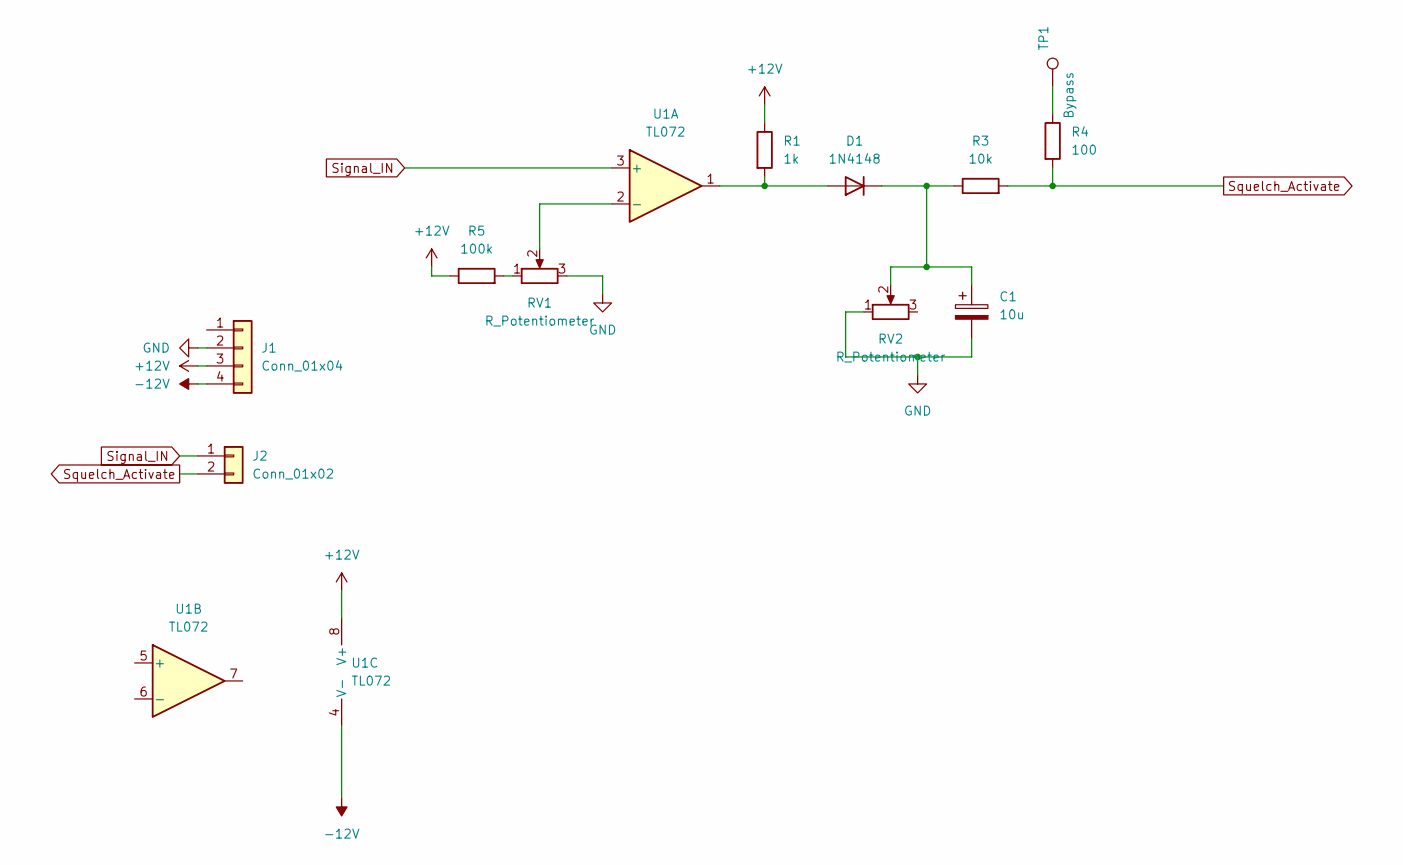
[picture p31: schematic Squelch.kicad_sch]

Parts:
C1: 10u; CP_Axial_L10.0mm_D6.0mm_P15.00mm_Horizontal
D1: 1N4148; D_DO-35_SOD27_P7.62mm_Horizontal
J1: Conn_01x04; PinHeader_1x04_P2.54mm_Vertical
J2: Conn_01x02; PinHeader_1x02_P2.54mm_Vertical
R1: 1k; R_Axial_DIN0207_L6.3mm_D2.5mm_P10.16mm_Horizontal
R3: 10k; R_Axial_DIN0207_L6.3mm_D2.5mm_P10.16mm_Horizontal
R4: 100; R_Axial_DIN0207_L6.3mm_D2.5mm_P10.16mm_Horizontal
R5: 100k; R_Axial_DIN0207_L6.3mm_D2.5mm_P10.16mm_Horizontal
RV1, RV2: R_Potentiometer; Potentiometer_Bourns_3386P_Vertical
TP1: Bypass; PinHeader_1x01_P2.54mm_Vertical
U1: TL072; DIP-8_W7.62mm_LongPads

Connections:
+12V: J1.3, R1.1, R5.1, U1.8 (V+)
-12V: J1.4, U1.4 (V-)
GND: C1.2, J1.2, RV1.3, RV2.1
unnamed: D1.2 (A), R1.2, U1.1
unnamed: C1.1, D1.1 (K), R3.1, RV2.2
unnamed: R4.1, TP1.1
unnamed: R5.2, RV1.1
unnamed: RV1.2, U1.2 (-)
Signal_IN: J2.1, U1.3 (+)
Squelch_Activate: J2.2, R3.2, R4.2

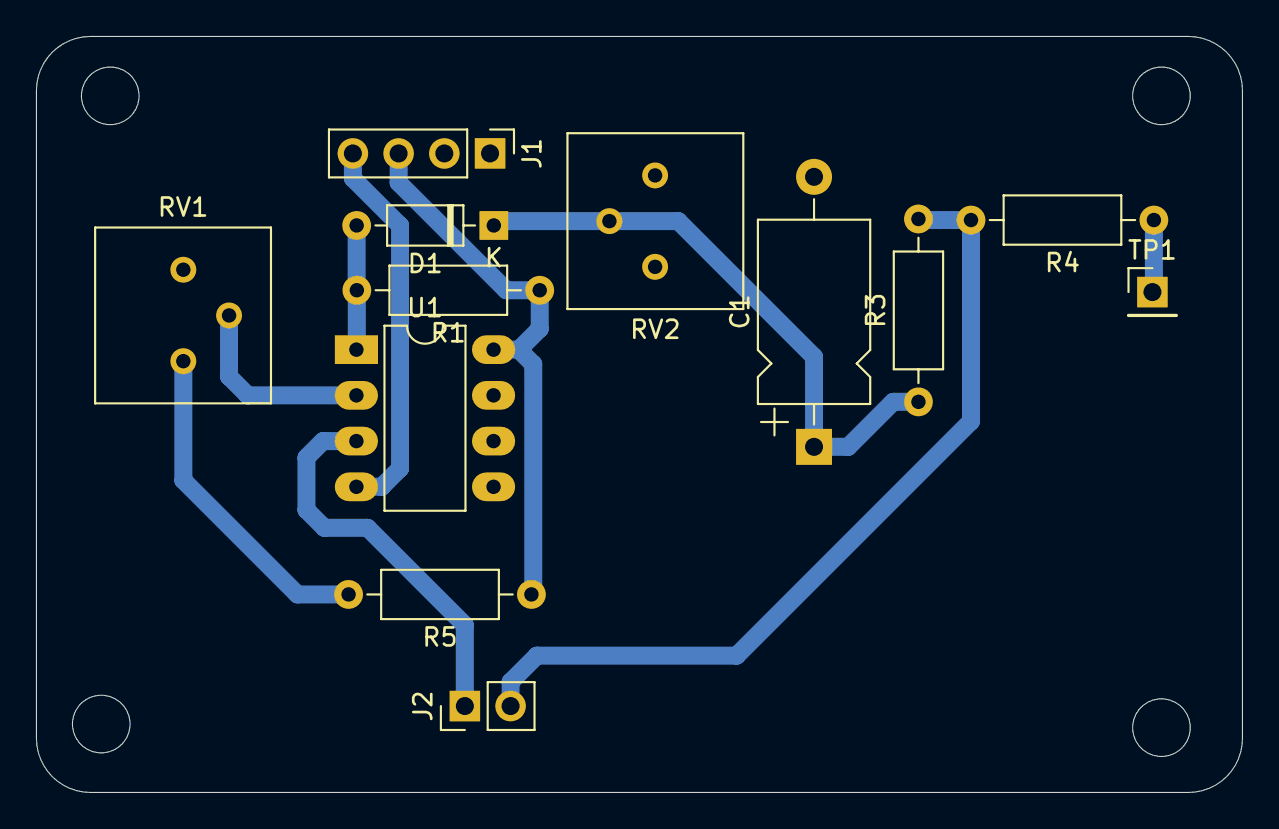
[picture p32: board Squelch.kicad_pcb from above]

Board: 2 copper layers, 67.0 x 42.0 mm, 12 parts (0 on the bottom side), 10 nets.

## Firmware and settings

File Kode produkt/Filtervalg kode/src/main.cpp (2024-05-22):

#include <Arduino.h>
#include <SoftwareSerial.h>
#include <SPI.h>
#include <TurboAnalogRead.h>

#include "Wire.h"

int S1 = 6; //S1S2
int S2 = 7; //Lunge
int S3 = 8; //Generel

float output1;
float output2;
float output3;

#define btn1 3 
#define btn2 4 
#define btn3 5 

int knapValg(){
  bool knap1 = digitalRead(btn1);
  bool knap2 = digitalRead(btn2);

  if(knap1 && !knap2){
    return 1;  
  }
  else if(knap2 && !knap1){
    return 2;
  }
  else if (knap1 && knap2){
    return 3;
  }
  else{
    return 0;
  }
}

void filterS1S2(){
  digitalWrite(S1, HIGH);
  digitalWrite(S2, LOW);
  digitalWrite(S3, LOW);
}

void filterLunge(){
  digitalWrite(S1, LOW);
  digitalWrite(S2, HIGH);
  digitalWrite(S3, LOW);
}

void filterGenerel(){
  digitalWrite(S1, LOW);
  digitalWrite(S2, LOW);
  digitalWrite(S3, HIGH);
}

void setup(){
  pinMode(btn1, INPUT);
  pinMode(btn2, INPUT);
  pinMode(btn3, INPUT);
  pinMode(S1, OUTPUT);
  pinMode(S2, OUTPUT);
  pinMode(S3, OUTPUT);
  pinMode(A0,INPUT);
  Serial.begin(921600);

TurboAnalogRead::Setup_timer(0,NULL);

TurboAnalogRead::Measure();


}

void loop(){
  int knapTryk = knapValg();

if(TurboAnalogRead::flag){
Serial.println(TurboAnalogRead::lastMeasurement);
TurboAnalogRead::flag = 0;
}

  if (knapTryk == 1){
    filterS1S2();
    }
  else if (knapTryk == 2){
    filterLunge();
  }
  else if (knapTryk == 3){
    filterGenerel();
  }
  
}
  

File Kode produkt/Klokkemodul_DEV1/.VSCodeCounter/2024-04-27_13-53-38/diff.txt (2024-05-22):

Date : 2024-04-27 13:53:38
Directory : c:\Users\Malthe Sennels\Documents\ESD210\Kode_Produkt\Klokkemodul_DEV1
Total : 0 files,  0 codes, 0 comments, 0 blanks, all 0 lines

Languages
+----------+------------+------------+------------+------------+------------+
| language | files      | code       | comment    | blank      | total      |
+----------+------------+------------+------------+------------+------------+
+----------+------------+------------+------------+------------+------------+

Directories
+------+------------+------------+------------+------------+------------+
| path | files      | code       | comment    | blank      | total      |
+------+------------+------------+------------+------------+------------+
+------+------------+------------+------------+------------+------------+

Files
+----------+----------+------------+------------+------------+------------+
| filename | language | code       | comment    | blank      | total      |
+----------+----------+------------+------------+------------+------------+
| Total    |          |          0 |          0 |          0 |          0 |
+----------+----------+------------+------------+------------+------------+

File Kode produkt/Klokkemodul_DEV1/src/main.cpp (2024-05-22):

#include <Arduino.h>
#include <HAL.h>
#include <Ringbuffer.h>
#include <RF24.h>


/**
 * @brief Den endelige kode til DEV1 boardet, med udgangspunkt i arduino UNO'en og Det sample 
 **/



/*************************************
 ** Delte funktioner og deres jobs
*/


/**********************************
 ** Delte semaforer og buffere
 */
SampleBuffer sampleBuffer; //buffer til vores... samples



void NewMeasurement(){ //Kode der bliver kørt hver gang der er taget en ny måling
  gainController.Update(TurboAnalogRead::lastMeasurement);
  if(sampleBuffer.Store(TurboAnalogRead::lastMeasurement)){
    //Queuer::Queue_INT(&SerializeJob, 30);
  }
}

void Readbuttons(uint16_t* buf){
  bool buttons[3] = {0};

  buttons[0] = digitalRead(4); //((PIND >> PD4) & 0x01);
  buttons[1] = digitalRead(5); //((PIND >> PD5) & 0x01);
  buttons[2] = digitalRead(6); //((PIND >> PD6) & 0x01);

  buf[0] |= ((uint16_t)buttons[0] << 10);
  buf[0] |= ((uint16_t)buttons[1] << 11);
  buf[0] |= ((uint16_t)buttons[2] << 12);
}

void setup() {

  gainController.begin();
  
  TurboAnalogRead::Setup_timer(ADCChannel, NewMeasurement); //sætter den funktion der skal kaldes ved nye måling op

  SetupRadio();

  pinMode(4, INPUT_PULLUP);
  pinMode(5, INPUT_PULLUP);
  pinMode(6, INPUT_PULLUP);
  
  TurboAnalogRead::Measure(); //starter timer
}
int inttt = 0;
uint16_t* outputBuffer;
void loop() {
  if(sampleBuffer.bufferReady()){
    cli();
    outputBuffer = sampleBuffer.Read();
    sei();
    Readbuttons(outputBuffer);
    bool result = radio.writeBlocking(outputBuffer, 32, 1); //!Evt brug writefast
  }
}
